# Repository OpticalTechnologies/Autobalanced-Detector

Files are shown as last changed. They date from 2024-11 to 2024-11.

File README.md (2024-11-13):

# Autobalanced-Detector
Full KiCAD design and production files of a self designed autobalanced detector for SRS microscopy. 

The autobalanced detector consists of three parts: 
1. Two of the same detectors (SRSDetV5_24V) to detect the signal and reference beam.
2. The autobalancer module.
3. The PID controller, which is designed as a seperate PCB controlled by an MCU. The MCU also controlls logic circuitry on the autobalancer module.

The SRSDetV5 is optimized for use with a 20MHz modulation frequency and incorperates several filters to supress the repetition rate of a 40MHz pulsed laser and its harmonics. 

Firmware for the PID MCU and instructions on how to upload the firmware to the MCU will follow.

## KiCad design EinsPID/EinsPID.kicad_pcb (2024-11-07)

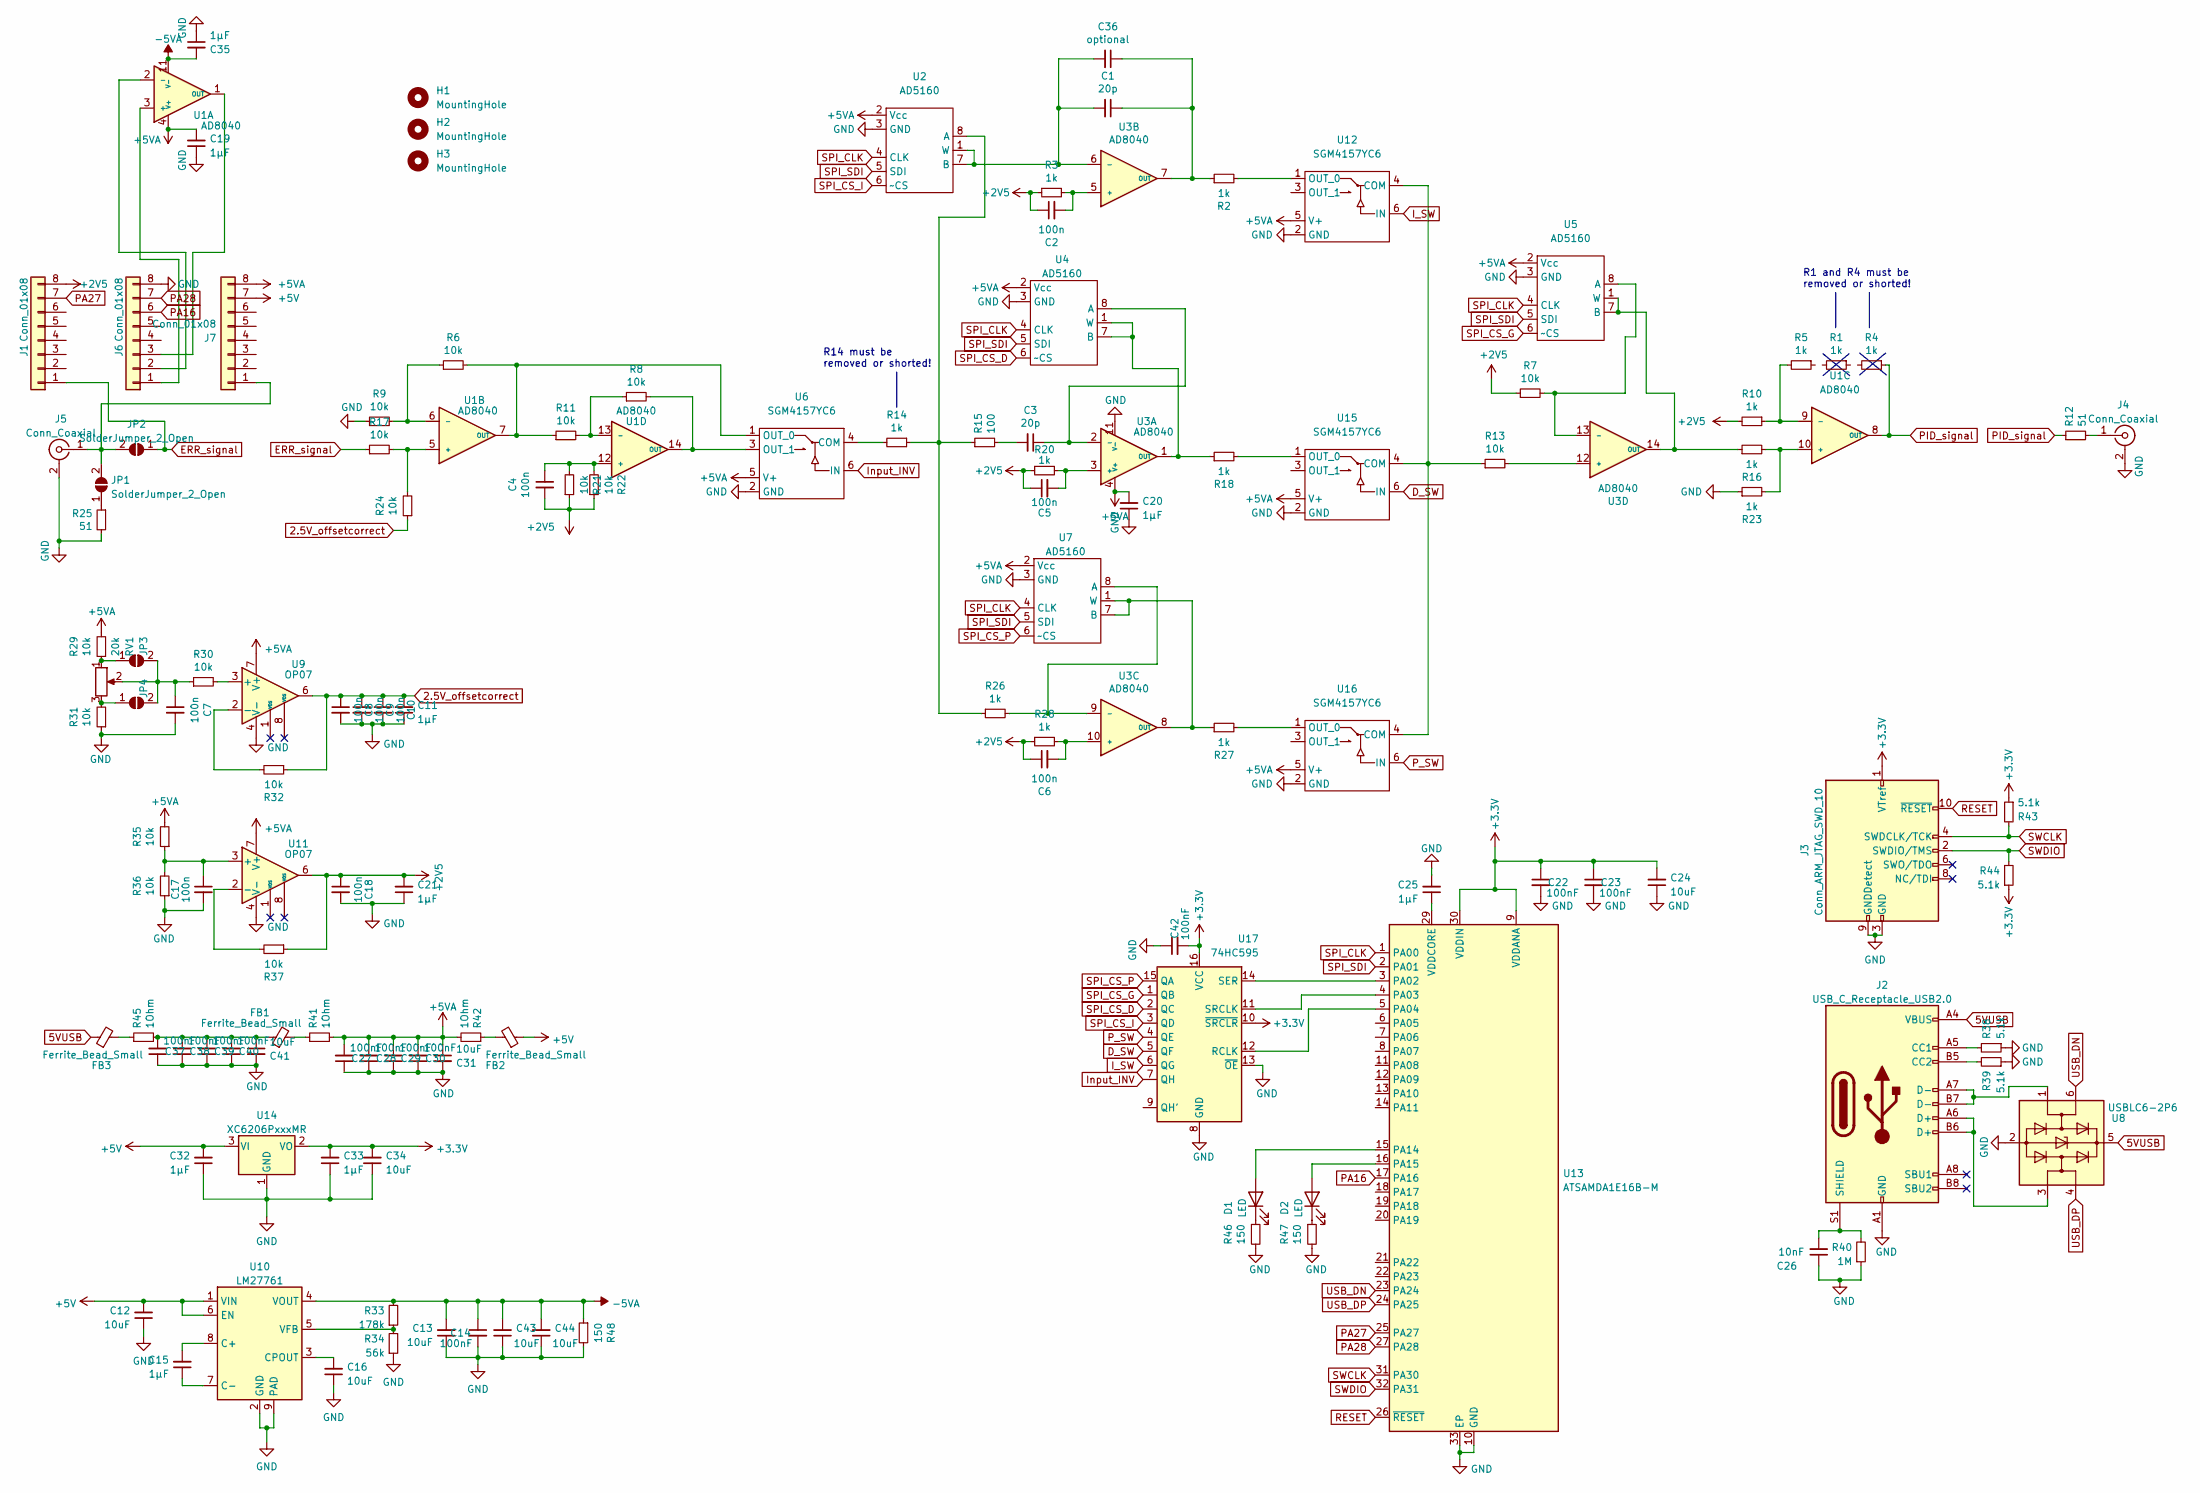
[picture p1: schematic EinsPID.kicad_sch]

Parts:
C1, C3: 20p; C_0402_1005Metric; LCSC C1554
C2, C4, C5, C6, C7, C8, C9, C10, C17, C18: 100n; C_0402_1005Metric; LCSC C1525
C11, C15, C19, C20, C21, C25, C32, C33, C35: 1µF; C_0402_1005Metric; LCSC C52923
C12, C13, C16, C24, C31, C34, C41, C43, C44: 10uF; C_0402_1005Metric; LCSC C386033
C14, C22, C23, C27, C28, C29, C30, C37, C38, C39, C40, C42: 100nF; C_0402_1005Metric; LCSC C307331
C26: 10nF; C_0402_1005Metric; LCSC C15195
C36: optional; C_Rect_L4.0mm_W2.5mm_P2.50mm
D1, D2: LED; LED_0603_1608Metric; LCSC C2286
FB1, FB2, FB3: Ferrite_Bead_Small; L_0603_1608Metric; LCSC C1002
H1: MountingHole; Logo_AGFallnich_text
H2: MountingHole; Logo_OptischeTechnologien
H3: MountingHole; Logo_WWU
J1, J6, J7: Conn_01x08; PinHeader_1x08_P2.54mm_Vertical
J2: USB_C_Receptacle_USB2.0; USB_C_Receptacle_XKB_U262-16XN-4BVC11; LCSC C709357
J3: Conn_ARM_JTAG_SWD_10; PinHeader_2x05_P1.27mm_Vertical_SMD
J4, J5: Conn_Coaxial; SMA_edge_pinholes
JP1, JP2, JP3, JP4: SolderJumper_2_Open; 0603_solderbridge
R1, R2, R3, R4, R5, R10, R14, R16, R18, R20, R23, R26, R27, R28: 1k; R_0402_1005Metric; LCSC C11702
R6, R7, R8, R9, R11, R13, R17, R21, R22, R24, R29, R30, R31, R32, R35, R36, R37: 10k; R_0402_1005Metric; LCSC C25744
R12, R25: 51; R_0402_1005Metric; LCSC C25125
R15: 100; R_0402_1005Metric; LCSC C25076
R33: 178k; R_0402_1005Metric; LCSC C26995
R34: 56k; R_0402_1005Metric; LCSC C25796
R38, R39, R43, R44: 5.1k; R_0402_1005Metric; LCSC C25905
R40: 1M; R_0402_1005Metric; LCSC C26083
R41, R42, R45: 1Ohm; R_0402_1005Metric; LCSC C25086
R46, R47, R48: 150; R_0402_1005Metric; LCSC C25082
RV1: 20k; Potentiometer_Bourns_3296W_Vertical
U1, U3: AD8040; SOIC-14_3.9x8.7mm_P1.27mm
U2, U4, U5, U7: AD5160; SOT-23-8; LCSC C40097
U6, U12, U15, U16: SGM4157YC6; SC-60; LCSC C124895
U8: USBLC6-2P6; SOT-666; LCSC C2827693
U9, U11: OP07; SOIC-8_3.9x4.9mm_P1.27mm; LCSC C7433
U10: LM27761; WSON-8-1EP_2x2mm_P0.5mm_EP0.9x1.6mm; LCSC C129351
U13: ATSAMDA1E16B-M; QFN-32-1EP_5x5mm_P0.5mm_EP3.6x3.6mm
U14: XC6206PxxxMR; SOT-23; LCSC C5446
U17: 74HC595; SOIC-16_3.9x9.9mm_P1.27mm; LCSC C5947

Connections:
2.5V_offsetcorrect: C8.1, C9.1, C10.1, C11.2, R24.1, R32.1, U9.6
5VUSB: FB3.1, J2.A4 (VBUS), J2.A9 (VBUS), J2.B4 (VBUS), J2.B9 (VBUS), U8.5 (VBUS)
+2V5: C2.1, C4.2, C5.1, C6.1, C18.1, C21.2, J1.8, R3.1, R7.1, R10.2, R20.1, R21.1, R22.1, R28.1, R37.1, U11.6
+3V3: C22.1, C23.1, C24.2, C33.2, C34.2, C42.2, J3.1 (VTref), R43.1, R44.1, U13.9 (VDDANA), U13.30 (VDDIN), U14.2 (VO), U17.10 (~SRCLR), U17.16 (VCC)
+5V: C12.2, C32.2, FB2.1, J7.7, U10.1 (VIN), U10.6 (EN), U14.3 (VI)
+5VA: C19.2, C20.2, C27.2, C28.2, C29.2, C30.2, C31.1, J7.8, R29.2, R35.2, R41.2, R42.2, U1.4 (V+), U2.2 (Vcc), U3.4 (V+), U4.2 (Vcc), U5.2 (Vcc), U6.5 (V+), U7.2 (Vcc), U9.7 (V+), U11.7 (V+), U12.5 (V+), U15.5 (V+), U16.5 (V+)
-5VA: C13.2, C14.1, C35.2, C43.2, C44.2, R33.2, R48.1, U1.11 (V-), U10.4 (VOUT)
D_SW: U15.6 (IN), U17.5 (QF)
ERR_signal: J1.1, JP2.1 (A), R17.1
GND: C7.2, C8.2, C9.2, C10.2, C11.1, C12.1, C13.1, C14.2, C16.1, C17.2, C18.2, C19.1, C20.1, C21.1, C22.2, C23.2, C24.1, C25.2, C26.1, C27.1, C28.1, C29.1, C30.1, C31.2, C32.1, C33.1, C34.1, C35.1, C37.1, C38.1, C39.1, C40.1, C41.2, C42.1, C43.1, C44.1, J2.A1 (GND), J2.A12 (GND), J2.B1 (GND), J2.B12 (GND), J3.3 (GND), J3.5 (GND), J3.9 (GNDDetect), J4.2 (Ext), J5.2 (Ext), J6.8, R9.1, R23.1, R25.2, R31.1, R34.1, R36.1, R38.1, R39.1, R40.1, R46.2, R47.2, R48.2, U2.3 (GND), U3.11 (V-), U4.3 (GND), U5.3 (GND), U6.2 (GND), U7.3 (GND), U8.2 (GND), U9.4 (V-), U10.2 (GND), U10.9 (PAD), U11.4 (V-), U12.2 (GND), U13.10 (GND), U13.28 (GND), U13.33 (EP), U14.1 (GND), U15.2 (GND), U16.2 (GND), U17.8 (GND), U17.13 (~OE)
I_SW: U12.6 (IN), U17.6 (QG)
Input_INV: U6.6 (IN), U17.7 (QH)
unnamed: C1.1, C36.1, R2.1, U3.7 (OUT)
unnamed: C1.2, C36.2, U2.1 (W), U2.7 (B), U3.6 (-)
unnamed: C2.2, R3.2, U3.5 (+)
unnamed: C3.1, U3.2 (-), U4.8 (A)
unnamed: C3.2, R15.2
unnamed: C4.1, R21.2, R22.2, U1.12 (+)
unnamed: C5.2, R20.2, U3.3 (+)
unnamed: C6.2, R28.2, U3.10 (+)
unnamed: C7.1, JP3.2 (B), JP4.2 (B), R30.1, RV1.2
unnamed: C15.1, U10.7 (C-)
unnamed: C15.2, U10.8 (C+)
unnamed: C16.2, U10.3 (CPOUT)
unnamed: C17.1, R35.1, R36.2, U11.3 (+)
unnamed: C25.1, U13.29 (VDDCORE)
unnamed: C26.2, J2.S1 (SHIELD), R40.2
unnamed: C37.2, C38.2, C39.2, C40.2, C41.1, FB1.1, R45.2
unnamed: D1.1 (K), R46.1
unnamed: D1.2 (A), U13.15 (PA14)
unnamed: D2.1 (K), R47.1
unnamed: D2.2 (A), U13.16 (PA15)
unnamed: FB1.2, R41.1
unnamed: FB2.2, R42.1
unnamed: FB3.2, R45.1
unnamed: J2.A5 (CC1), R38.2
unnamed: J2.A6 (D+), J2.B6 (D+), U8.3 (I/O2)
unnamed: J2.A7 (D-), J2.B7 (D-), U8.1 (I/O1)
unnamed: J2.B5 (CC2), R39.2
unnamed: J4.1 (In), R12.2
unnamed: J5.1 (In), J7.1, JP1.2 (B), JP2.2 (B)
unnamed: J6.1, U1.3 (+)
unnamed: J6.2, U1.2 (-)
unnamed: J6.3, U1.1 (OUT)
unnamed: JP1.1 (A), R25.1
unnamed: JP3.1 (A), R29.1, RV1.1
unnamed: JP4.1 (A), R31.2, RV1.3
unnamed: R1.1, R4.2
unnamed: R1.2, R5.1
unnamed: R2.2, U12.1 (OUT_0)
unnamed: R6.1, R9.2, U1.6 (-)
unnamed: R7.2, U3.13 (-), U5.8 (A)
unnamed: R8.2, U1.14 (OUT), U6.3 (OUT_1)
unnamed: R5.2, R10.1, U1.9 (-)
unnamed: R6.2, R11.1, U1.7 (OUT), U6.1 (OUT_0)
unnamed: R8.1, R11.2, U1.13 (-)
unnamed: R13.1, U12.4 (COM), U15.4 (COM), U16.4 (COM)
unnamed: R13.2, U3.12 (+)
unnamed: R14.1, R15.1, R26.1, U2.8 (A)
unnamed: R16.1, U3.14 (OUT), U5.1 (W), U5.7 (B)
unnamed: R16.2, R23.2, U1.10 (+)
unnamed: R17.2, R24.2, U1.5 (+)
unnamed: R18.1, U3.1 (OUT), U4.1 (W), U4.7 (B)
unnamed: R18.2, U15.1 (OUT_0)
unnamed: R26.2, U3.9 (-), U7.8 (A)
unnamed: R27.1, U3.8 (OUT), U7.1 (W), U7.7 (B)
unnamed: R27.2, U16.1 (OUT_0)
unnamed: R30.2, U9.3 (+)
unnamed: R32.2, U9.2 (-)
unnamed: R33.1, R34.2, U10.5 (VFB)
unnamed: R37.2, U11.2 (-)
unnamed: R14.2, U6.4 (COM)
unnamed: U13.3 (PA02), U17.14 (SER)
unnamed: U13.4 (PA03), U17.11 (SRCLK)
unnamed: U13.5 (PA04), U17.12 (RCLK)
PA16: J6.6, U13.17 (PA16)
PA27: J1.7, U13.25 (PA27)
PA28: J6.7, U13.27 (PA28)
PID_signal: R4.1, R12.1, U1.8 (OUT)
P_SW: U16.6 (IN), U17.4 (QE)
RESET: J3.10 (~RESET), U13.26 (~RESET)
SPI_CLK: U2.4 (CLK), U4.4 (CLK), U5.4 (CLK), U7.4 (CLK), U13.1 (PA00)
SPI_CS_D: U4.6 (~CS), U17.2 (QC)
SPI_CS_G: U5.6 (~CS), U17.1 (QB)
SPI_CS_I: U2.6 (~CS), U17.3 (QD)
SPI_CS_P: U7.6 (~CS), U17.15 (QA)
SPI_SDI: U2.5 (SDI), U4.5 (SDI), U5.5 (SDI), U7.5 (SDI), U13.2 (PA01)
SWCLK: J3.4 (SWDCLK/TCK), R43.2, U13.31 (PA30)
SWDIO: J3.2 (SWDIO/TMS), R44.2, U13.32 (PA31)
USB_DN: U8.6 (I/O1), U13.23 (PA24)
USB_DP: U8.4 (I/O2), U13.24 (PA25)

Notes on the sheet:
R14 must be removed or shorted!
R1 and R4 must be removed or shorted!

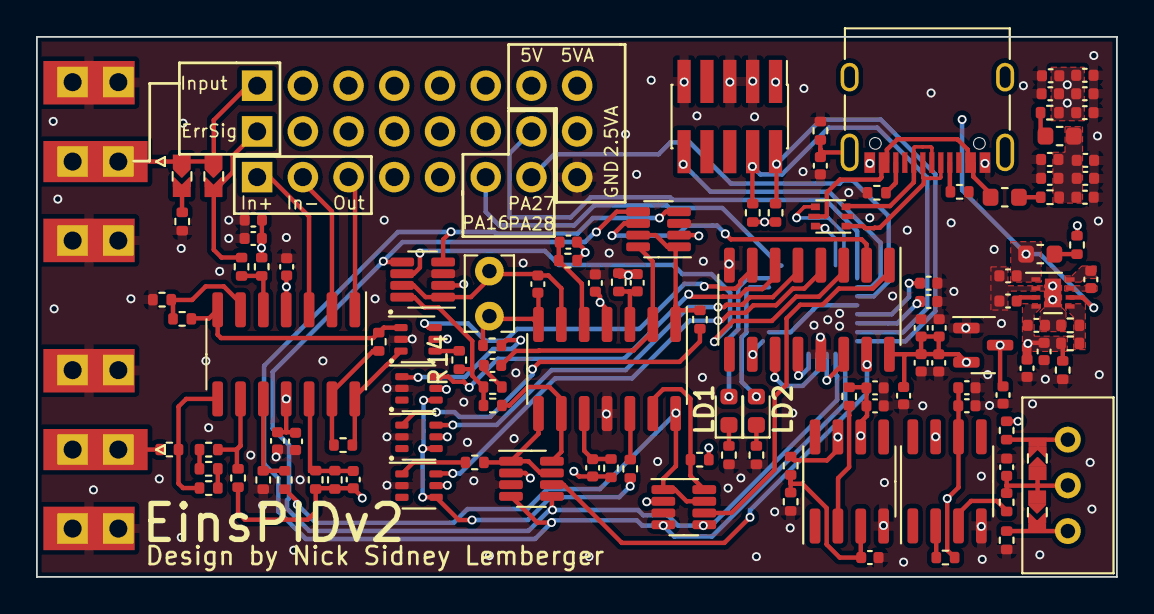
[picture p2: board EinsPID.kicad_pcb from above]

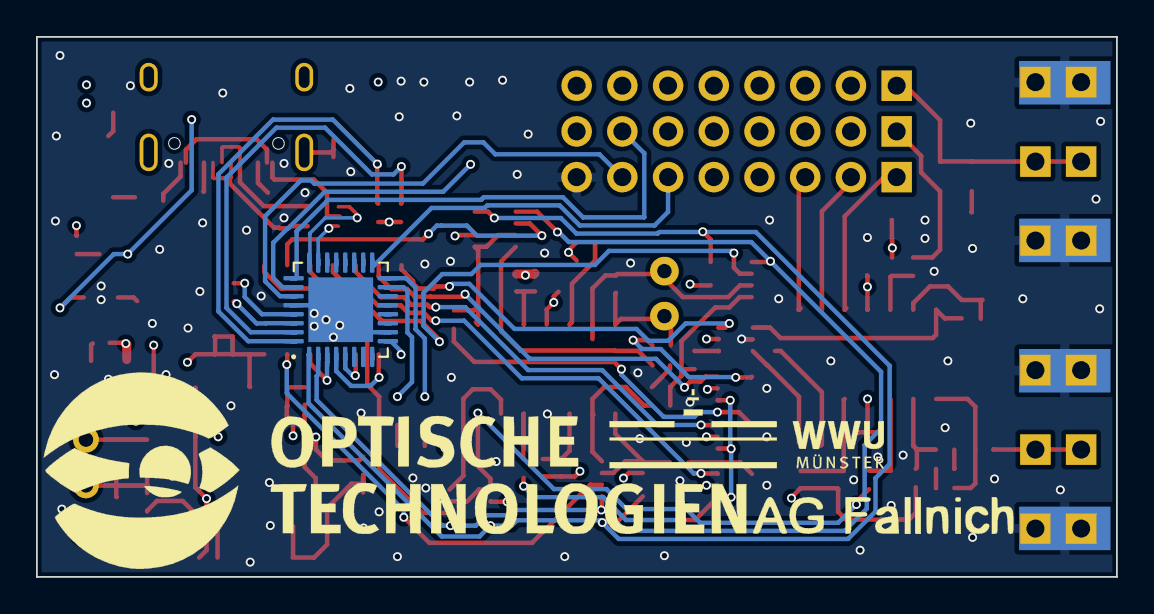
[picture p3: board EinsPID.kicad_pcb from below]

Board: 4 copper layers, 60.0 x 30.0 mm, 128 parts (4 on the bottom side), 91 nets.

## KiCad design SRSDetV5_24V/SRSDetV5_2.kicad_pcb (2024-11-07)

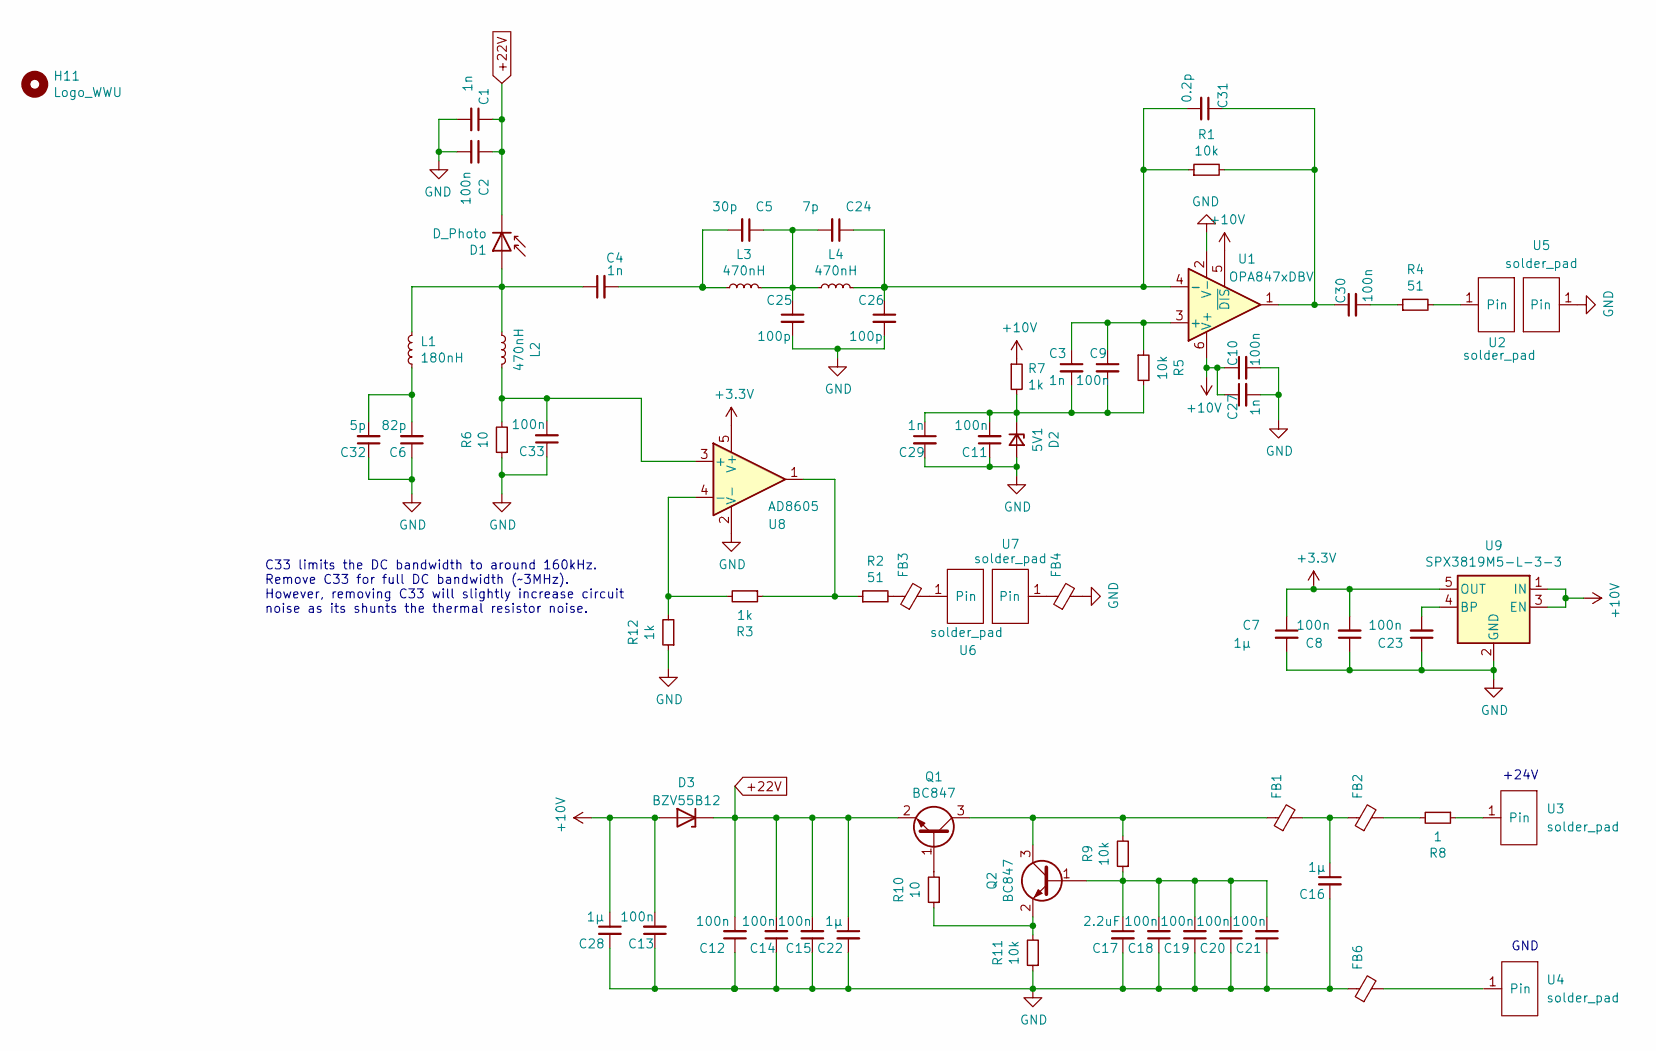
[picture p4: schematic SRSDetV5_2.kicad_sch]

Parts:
C1, C3, C4, C27, C29: 1n; C_0402_1005Metric; LCSC C1523
C2, C8, C9, C10, C11, C12, C13, C14, C15, C18, C19, C20, C21, C23, C30, C33: 100n; C_0402_1005Metric; LCSC C1525
C5: 30p; C_0402_1005Metric; LCSC C1570
C6: 82p; C_0402_1005Metric; LCSC C13532
C7, C16, C22, C28: 1µ; C_0402_1005Metric; LCSC C52923
C17: 2.2uF; C_1206_3216Metric; LCSC C50254
C24: 7p; C_0402_1005Metric; LCSC C114403
C25, C26: 100p; C_0402_1005Metric; LCSC C1546
C31: 0.2p; C_0402_1005Metric; LCSC C161339
C32: 5p; C_0402_1005Metric; LCSC C880630
D1: D_Photo; S3590-xx
D2: 5V1; D_SOD-323; LCSC C173436
D3: BZV55B12; D_MiniMELF; LCSC C545385
FB1, FB2, FB3, FB4, FB6: Ferrite_Bead_Small; L_0603_1608Metric; LCSC C1002
H11: Logo_WWU
L1: 180nH; L_0805_2012Metric; LCSC C251836
L2, L3, L4: 470nH; L_0603_1608Metric; LCSC C127457
Q1, Q2: BC847; SOT-23; LCSC C8664
R1: 10k; R_0402_1005Metric; LCSC C84351
R2, R4: 51; R_0402_1005Metric; LCSC C25125
R3, R7, R12: 1k; R_0402_1005Metric; LCSC C328418
R5, R9, R11: 10k; R_0402_1005Metric; LCSC C25744
R6: 10; R_0402_1005Metric; LCSC C319916
R8: 1; R_0402_1005Metric; LCSC C25086
R10: 10; R_0402_1005Metric; LCSC C25077
U1: OPA847xDBV; SOT-23-6; LCSC C160422
U2, U3, U4, U5, U6, U7: solder_pad
U8: AD8605; SOT-23-5; LCSC C9641
U9: SPX3819M5-L-3-3; SOT-23-5; LCSC C9055

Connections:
+3V3: C7.1, C8.2, U8.5 (V+), U9.5 (OUT)
+10V: C10.1, C13.2, C27.1, C28.1, D3.2 (A), R7.1, U1.5 (~DIS), U1.6 (V+), U9.1 (IN), U9.3 (EN)
+22V: C1.1, C2.1, C12.2, C14.2, C15.2, C22.1, D1.1 (K), D3.1 (K), Q1.2 (E)
GND: C1.2, C2.2, C6.1, C7.2, C8.1, C10.2, C11.1, C12.1, C13.1, C14.1, C15.1, C16.2, C17.2, C18.1, C19.1, C20.1, C21.1, C22.2, C23.1, C25.2, C26.2, C27.2, C28.2, C29.2, C32.1, C33.1, D2.2 (A), FB4.2, FB6.1, R6.1, R11.1, R12.1, U1.2 (V-), U5.1, U8.2 (V-), U9.2 (GND)
unnamed: C3.1, C9.1, R5.1, U1.3 (+)
unnamed: C4.1, D1.2 (A), L1.2, L2.1
unnamed: C4.2, C5.2, L3.1
unnamed: C3.2, C9.2, C11.2, C29.1, D2.1 (K), R5.2, R7.2
unnamed: C16.1, FB1.2, FB2.1
unnamed: C17.1, C18.2, C19.2, C20.2, C21.2, Q2.1 (B), R9.1
unnamed: C23.2, U9.4 (BP)
unnamed: C24.1, C26.1, C31.2, L4.2, R1.1, U1.4 (-)
unnamed: C5.1, C24.2, C25.1, L3.2, L4.1
unnamed: C30.1, C31.1, R1.2, U1.1
unnamed: C30.2, R4.1
unnamed: C6.2, C32.2, L1.1
unnamed: C33.2, L2.2, R6.2, U8.3 (+)
unnamed: FB1.1, Q1.3 (C), Q2.3 (C), R9.2
unnamed: FB2.2, R8.2
unnamed: FB3.1, R2.2
unnamed: FB3.2, U6.1
unnamed: FB4.1, U7.1
unnamed: Q1.1 (B), R10.2
unnamed: Q2.2 (E), R10.1, R11.2
unnamed: R2.1, R3.1, U8.1
unnamed: R4.2, U2.1
unnamed: R8.1, U3.1
unnamed: R3.2, R12.2, U8.4 (-)

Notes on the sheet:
+24V
C33 limits the DC bandwidth to around 160kHz. Remove C33 for full DC bandwidth (~3MHz). However, removing C33 will slightly increase circuit noise as its shunts the thermal resistor noise.
GND

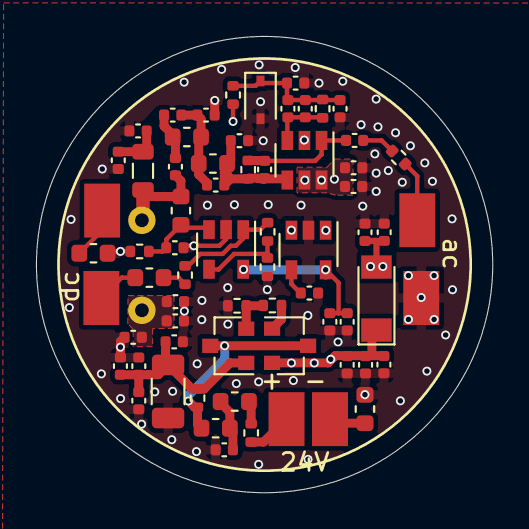
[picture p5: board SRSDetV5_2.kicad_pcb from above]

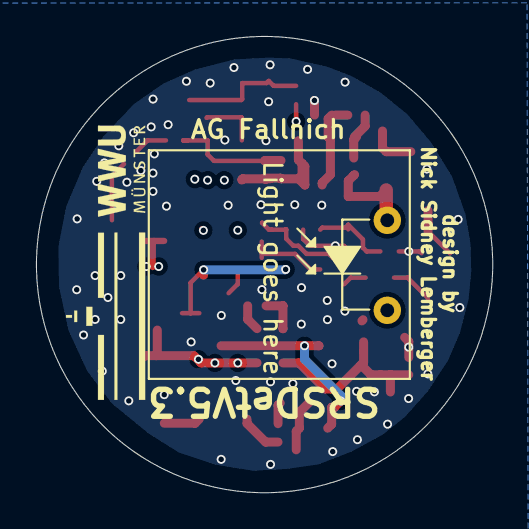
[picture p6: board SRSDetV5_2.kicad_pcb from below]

Board: 4 copper layers, 25.3 x 25.3 mm, 69 parts (2 on the bottom side), 28 nets.

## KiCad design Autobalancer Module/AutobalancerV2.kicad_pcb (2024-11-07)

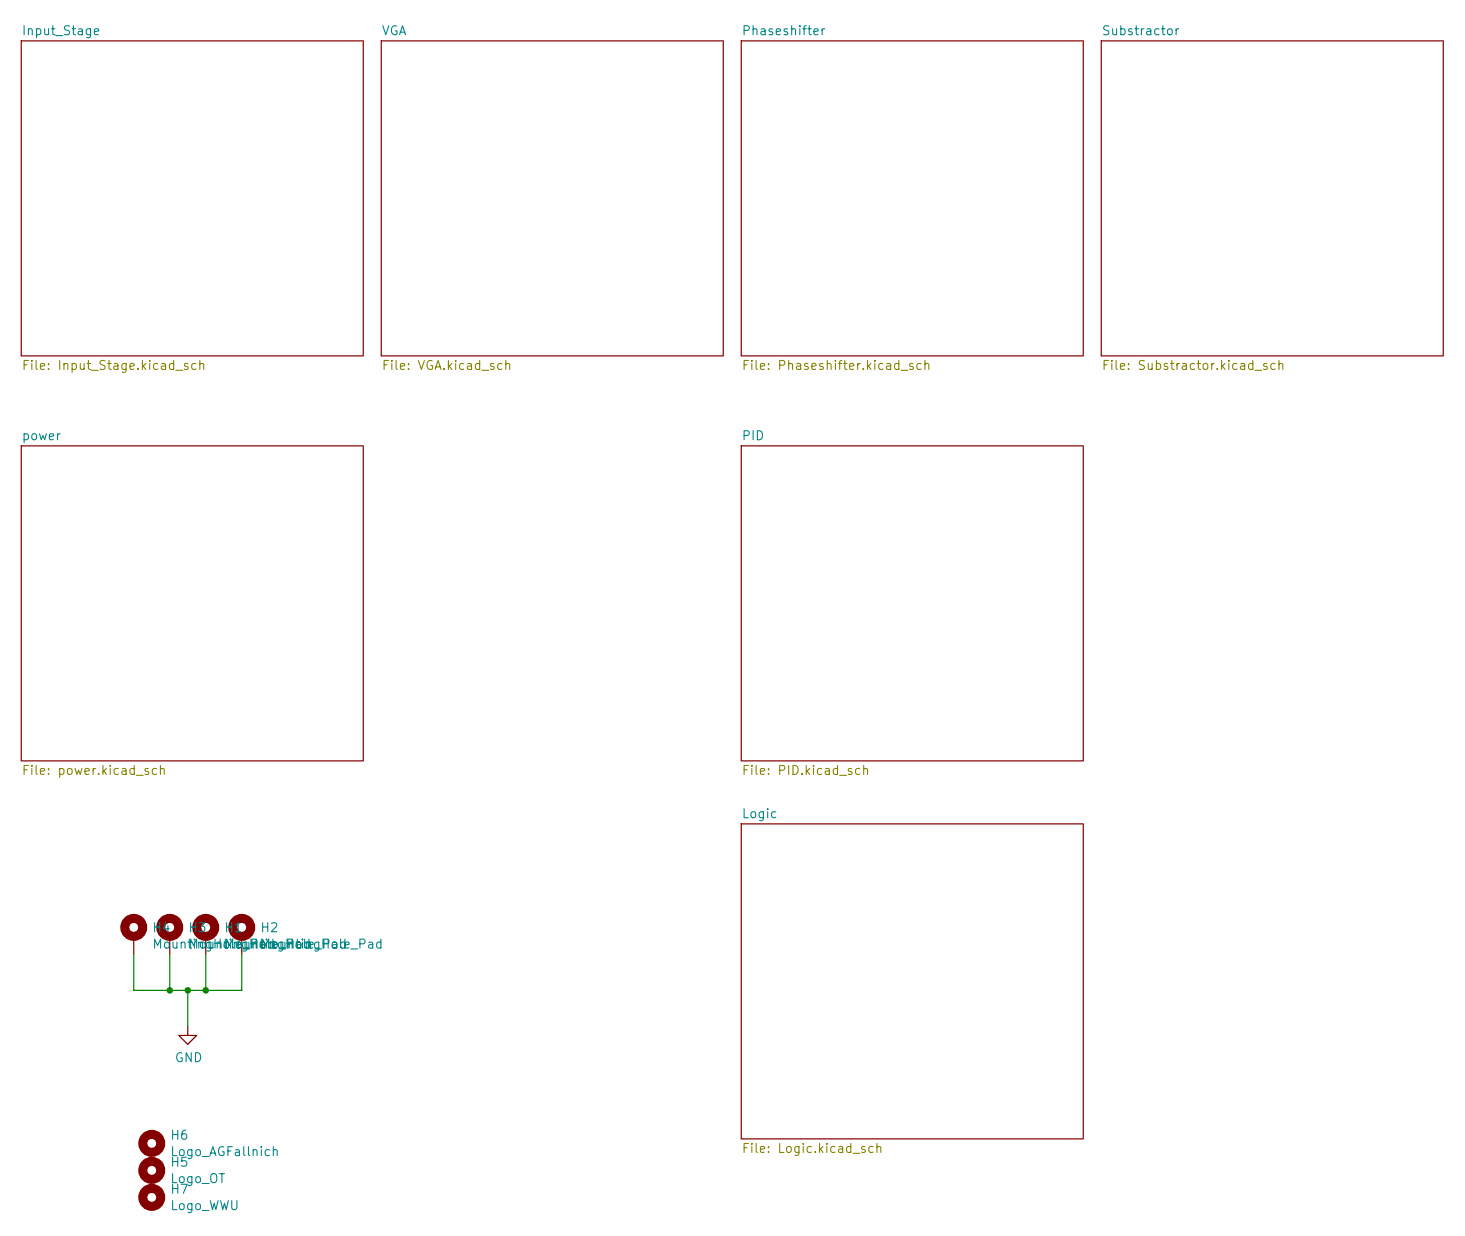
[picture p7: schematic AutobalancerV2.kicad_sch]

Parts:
H1, H2, H3, H4: MountingHole_Pad; MountingHole_3.2mm_M3_Pad_Via
H5: Logo_OT; Logo_OptischeTechnologien
H6: Logo_AGFallnich; Logo_AGFallnich_text
H7: Logo_WWU

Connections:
GND: H1.1, H2.1, H3.1, H4.1; also elsewhere on the board

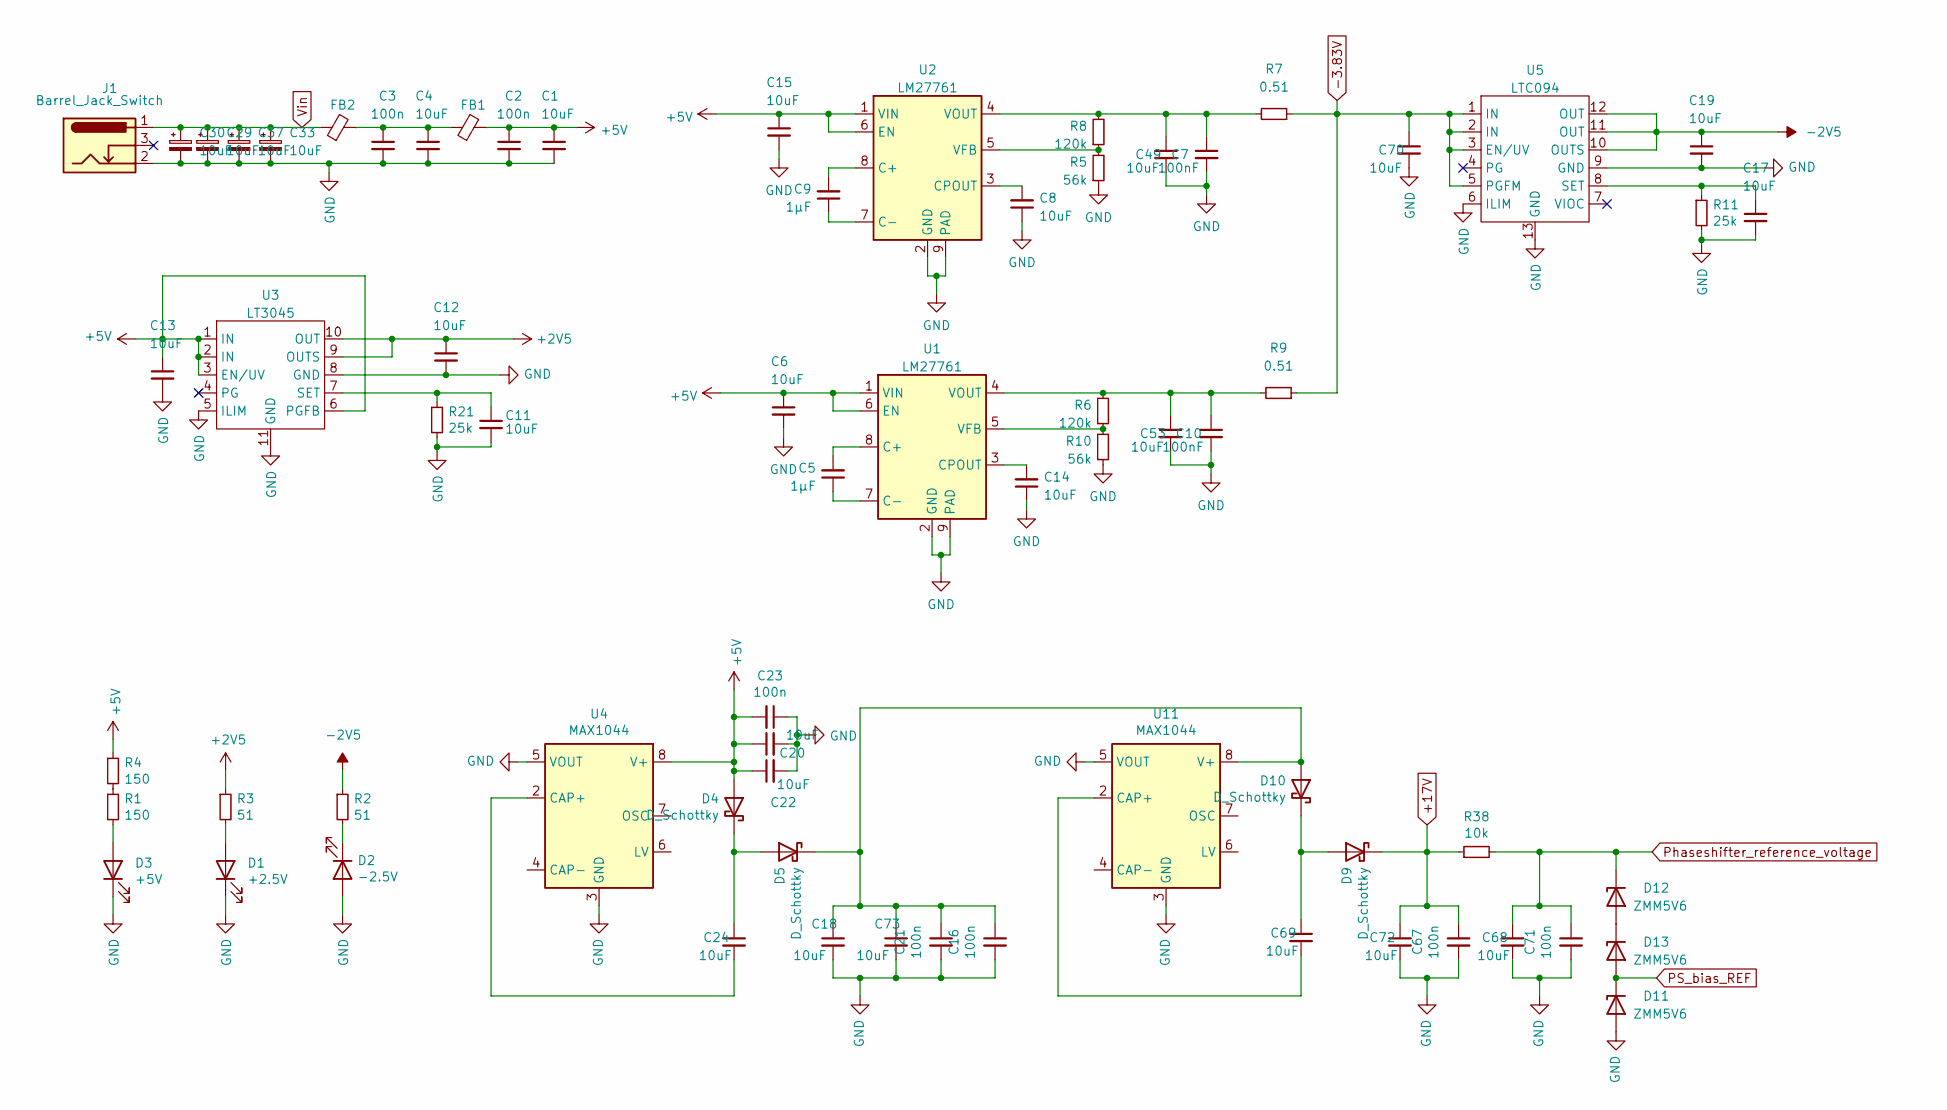
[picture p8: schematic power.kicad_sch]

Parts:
C1, C4, C6, C11, C12, C13, C15, C17, C18, C19, C20, C22, C24, C49, C53, C68, C69, C70, C72, C73: 10uF; C_1206_3216Metric; LCSC C13585
C2, C3, C16, C21, C23, C67, C71: 100n; C_0402_1005Metric; LCSC C1525
C5, C9: 1µF; C_0402_1005Metric; LCSC C52923
C7, C10: 100nF; C_0402_1005Metric; LCSC C307331
C8, C14: 10uF; C_0402_1005Metric; LCSC C386033
C29, C30, C33, C37: 10uF; CP_EIA-3216-18_Kemet-A; LCSC C7171
D1: +2.5V; LED_0603_1608Metric; LCSC C2286
D2: -2.5V; LED_0603_1608Metric; LCSC C2286
D3: +5V; LED_0603_1608Metric; LCSC C2286
D4, D5, D9, D10: D_Schottky; D_SOD-123; LCSC C8598
D11, D12, D13: ZMM5V6; D_MiniMELF; LCSC C8062
FB1, FB2: Ferrite_Bead_Small; L_0805_2012Metric; LCSC C74323
J1: Barrel_Jack_Switch; BarrelJack_CUI_PJ-102AH_Horizontal_with3D
R1, R4: 150; R_0402_1005Metric; LCSC C25082
R2, R3: 51; R_0402_1005Metric; LCSC C25125
R5, R10: 56k; R_0402_1005Metric; LCSC C25796
R6, R8: 120k; R_0402_1005Metric; LCSC C25750
R7, R9: 0.51; R_0402_1005Metric; LCSC C423100
R11, R21: 25k; R_0805_2012Metric; LCSC C316201
R38: 10k; R_0402_1005Metric; LCSC C25744
U1, U2: LM27761; WSON-8-1EP_2x2mm_P0.5mm_EP0.9x1.6mm; LCSC C129351
U3: LT3045; DFN-10-1EP_3x3mm_P0.5mm_EP1.65x2.38mm; LCSC C666574
U4, U11: MAX1044; SOIC-8_3.9x4.9mm_P1.27mm; LCSC C140450
U5: LTC094; DFN-12-1EP_3x3mm_P0.45mm_EP1.66x2.38mm

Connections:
+2V5: C12.1, R3.1, U3.9 (OUTS), U3.10 (OUT); also elsewhere on the board
+5V: C1.1, C2.1, C6.1, C13.1, C15.1, C20.1, C22.1, C23.2, D4.2 (A), FB1.2, R4.1, U1.1 (VIN), U1.6 (EN), U2.1 (VIN), U2.6 (EN), U3.1 (IN), U3.2 (IN), U3.3 (EN/UV), U3.6 (PGFB), U4.8 (V+); also elsewhere on the board
+17V: C67.1, C72.1, D9.1 (K), R38.1; also elsewhere on the board
-2V5: C19.1, R2.1, U5.10 (OUTS), U5.11 (OUT), U5.12 (OUT); also elsewhere on the board
-3.83V: C70.1, R7.1, R9.1, U5.1 (IN), U5.2 (IN), U5.3 (EN/UV), U5.5 (PGFM)
GND: C1.2, C2.2, C3.2, C4.2, C6.2, C7.2, C8.1, C10.2, C11.2, C12.2, C13.2, C14.1, C15.2, C16.2, C17.2, C18.2, C19.2, C20.2, C21.2, C22.2, C23.1, C29.2, C30.2, C33.2, C37.2, C49.2, C53.2, C67.2, C68.2, C70.2, C71.2, C72.2, C73.2, D1.1 (K), D2.2 (A), D3.1 (K), D11.2 (A), J1.2, R5.1, R10.1, R11.2, R21.2, U1.2 (GND), U1.9 (PAD), U2.2 (GND), U2.9 (PAD), U3.5 (ILIM), U3.8 (GND), U3.11 (GND), U4.3 (GND), U4.5 (VOUT), U5.6 (ILIM), U5.9 (GND), U5.13 (GND), U11.3 (GND), U11.5 (VOUT); also elsewhere on the board
unnamed: C3.1, C4.1, FB1.1, FB2.2
unnamed: C5.1, U1.7 (C-)
unnamed: C5.2, U1.8 (C+)
unnamed: C8.2, U2.3 (CPOUT)
unnamed: C9.1, U2.7 (C-)
unnamed: C9.2, U2.8 (C+)
unnamed: C10.1, C53.1, R6.2, R9.2, U1.4 (VOUT)
unnamed: C11.1, R21.1, U3.7 (SET)
unnamed: C14.2, U1.3 (CPOUT)
unnamed: C16.1, C18.1, C21.1, C73.1, D5.1 (K), D10.2 (A), U11.8 (V+)
unnamed: C17.1, R11.1, U5.8 (SET)
unnamed: C24.1, D4.1 (K), D5.2 (A)
unnamed: C24.2, U4.2 (CAP+)
unnamed: C7.1, C49.1, R7.2, R8.2, U2.4 (VOUT)
unnamed: C69.1, D9.2 (A), D10.1 (K)
unnamed: C69.2, U11.2 (CAP+)
unnamed: D1.2 (A), R3.2
unnamed: D2.1 (K), R2.2
unnamed: D3.2 (A), R1.2
unnamed: D12.2 (A), D13.1 (K)
unnamed: R1.1, R4.2
unnamed: R5.2, R8.1, U2.5 (VFB)
unnamed: R6.1, R10.2, U1.5 (VFB)
PS_bias_REF: D11.1 (K), D13.2 (A); also elsewhere on the board
Phaseshifter_reference_voltage: C68.1, C71.1, D12.1 (K), R38.2; also elsewhere on the board
Vin: C29.1, C30.1, C33.1, C37.1, FB2.1, J1.1; also elsewhere on the board

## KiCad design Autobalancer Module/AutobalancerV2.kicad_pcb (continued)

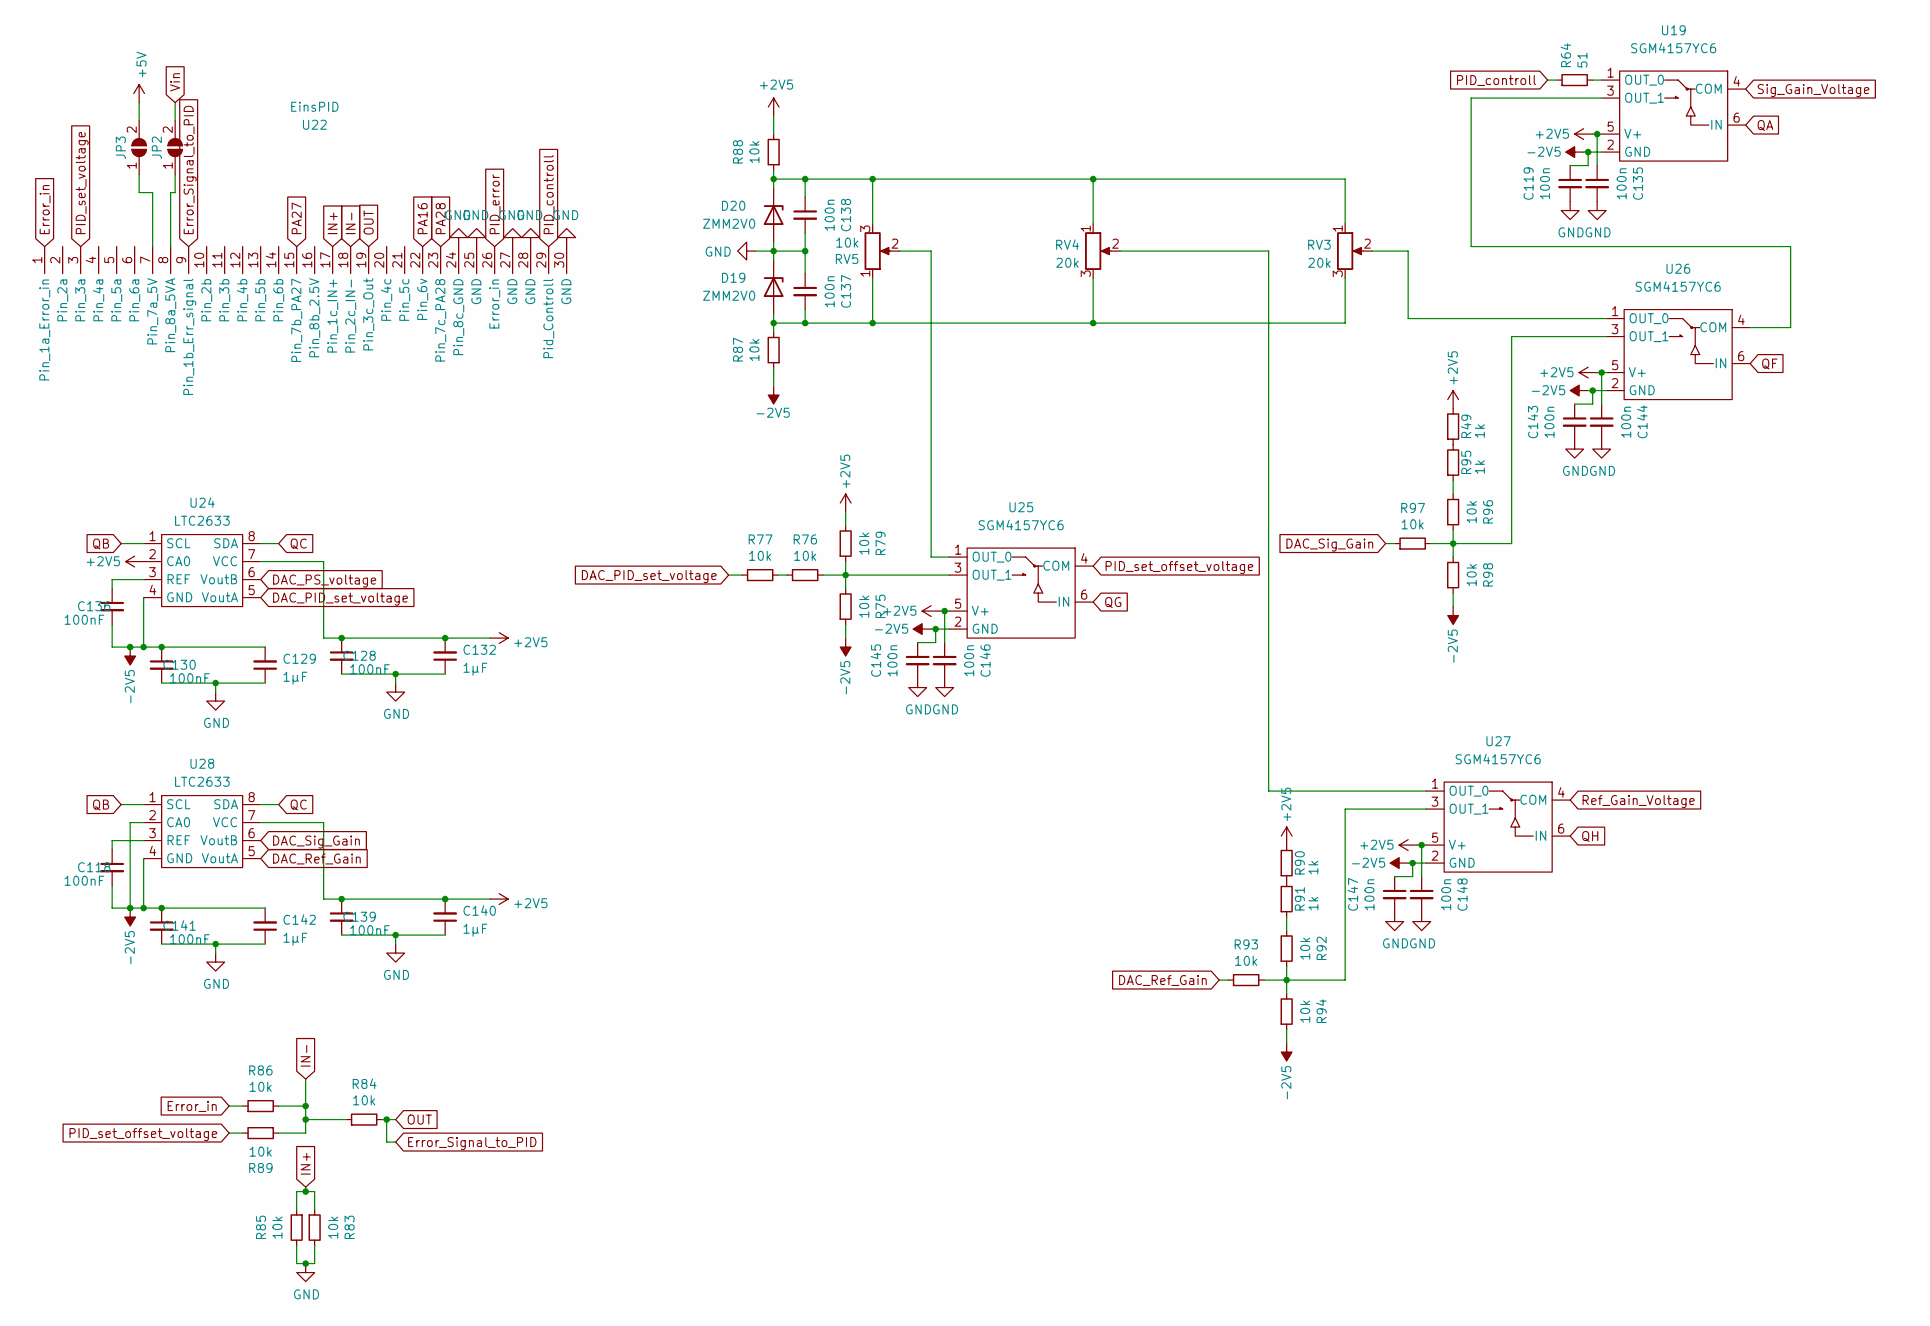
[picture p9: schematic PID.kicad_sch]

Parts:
C118, C128, C130, C136, C139, C141: 100nF; C_0402_1005Metric; LCSC C307331
C119, C135, C137, C138, C143, C144, C145, C146, C147, C148: 100n; C_0402_1005Metric; LCSC C1525
C129, C132, C140, C142: 1µF; C_0402_1005Metric; LCSC C52923
D19, D20: ZMM2V0; D_MiniMELF; LCSC C8079
JP2, JP3: SolderJumper_2_Open; 0603_solderbridge
R49, R90, R91, R95: 1k; R_0402_1005Metric; LCSC C11702
R64: 51; R_0402_1005Metric; LCSC C25125
R75, R76, R77, R79, R83, R84, R85, R86, R87, R88, R89, R92, R93, R94, R96, R97, R98: 10k; R_0402_1005Metric; LCSC C25744
RV3, RV4: 20k; Potentiometer_Bourns_3296W_Vertical
RV5: 10k; Potentiometer_Bourns_3296W_Vertical
U19, U25, U26, U27: SGM4157YC6; SC-60; LCSC C124895
U22: EinsPID
U24, U28: LTC2633; SOT-23-8

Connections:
+2V5: C128.1, C132.2, C135.1, C139.1, C140.2, C144.1, C146.1, C148.1, R49.2, R79.2, R88.2, R90.2, U19.5 (V+), U24.2 (CA0), U24.7 (VCC), U25.5 (V+), U26.5 (V+), U27.5 (V+), U28.7 (VCC); also elsewhere on the board
+5V: JP3.2 (B); also elsewhere on the board
-2V5: C118.2, C119.1, C129.2, C130.1, C136.2, C141.1, C142.2, C143.1, C145.1, C147.1, R75.1, R87.1, R94.1, R98.1, U19.2 (GND), U24.4 (GND), U25.2 (GND), U26.2 (GND), U27.2 (GND), U28.2 (CA0), U28.4 (GND); also elsewhere on the board
DAC_PID_set_voltage: R77.1, U24.5 (VoutA)
DAC_PS_voltage: U24.6 (VoutB); also elsewhere on the board
DAC_Ref_Gain: R93.1, U28.5 (VoutA)
DAC_Sig_Gain: R97.1, U28.6 (VoutB)
Error_Signal_to_PID: R84.2, U22.9 (Pin_1b_Err_signal), U22.19 (Pin_3c_Out)
Error_in: R86.1, U22.1 (Pin_1a_Error_in)
GND: C119.2, C128.2, C129.1, C130.2, C132.1, C135.2, C137.1, C138.2, C139.2, C140.1, C141.2, C142.1, C143.2, C144.2, C145.2, C146.2, C147.2, C148.2, D19.1 (K), D20.2 (A), R83.2, R85.2, U22.24 (Pin_8c_GND), U22.25 (GND), U22.27 (GND), U22.28 (GND), U22.30 (GND); also elsewhere on the board
IN+: R83.1, R85.1, U22.17 (Pin_1c_IN+)
IN-: R84.1, R86.2, R89.1, U22.18 (Pin_2c_IN-)
unnamed: C118.1, U28.3 (REF)
unnamed: C136.1, U24.3 (REF)
unnamed: C137.2, D19.2 (A), R87.2, RV3.3, RV4.3, RV5.1
unnamed: C138.1, D20.1 (K), R88.1, RV3.1, RV4.1, RV5.3
unnamed: JP2.1 (A), U22.8 (Pin_8a_5VA)
unnamed: JP3.1 (A), U22.7 (Pin_7a_5V)
unnamed: R49.1, R95.2
unnamed: R64.2, U19.1 (OUT_0)
unnamed: R75.2, R76.2, R79.1, U25.3 (OUT_1)
unnamed: R76.1, R77.2
unnamed: R90.1, R91.2
unnamed: R91.1, R92.2
unnamed: R92.1, R93.2, R94.2, U27.3 (OUT_1)
unnamed: R95.1, R96.2
unnamed: R96.1, R97.2, R98.2, U26.3 (OUT_1)
unnamed: RV3.2, U26.1 (OUT_0)
unnamed: RV4.2, U27.1 (OUT_0)
unnamed: RV5.2, U25.1 (OUT_0)
unnamed: U19.3 (OUT_1), U26.4 (COM)
PA16: U22.22 (Pin_6v); also elsewhere on the board
PA27: U22.15 (Pin_7b_PA27); also elsewhere on the board
PA28: U22.23 (Pin_7c_PA28); also elsewhere on the board
PID_controll: R64.1, U22.29 (Pid_Controll)
PID_error: U22.26 (Error_in); also elsewhere on the board
PID_set_offset_voltage: R89.2, U25.4 (COM)
PID_set_voltage: U22.3 (Pin_3a)
QA: U19.6 (IN); also elsewhere on the board
QB: U24.1 (SCL), U28.1 (SCL); also elsewhere on the board
QC: U24.8 (SDA), U28.8 (SDA); also elsewhere on the board
QF: U26.6 (IN); also elsewhere on the board
QG: U25.6 (IN); also elsewhere on the board
QH: U27.6 (IN); also elsewhere on the board
Ref_Gain_Voltage: U27.4 (COM); also elsewhere on the board
Sig_Gain_Voltage: U19.4 (COM); also elsewhere on the board
Vin: JP2.2 (B); also elsewhere on the board

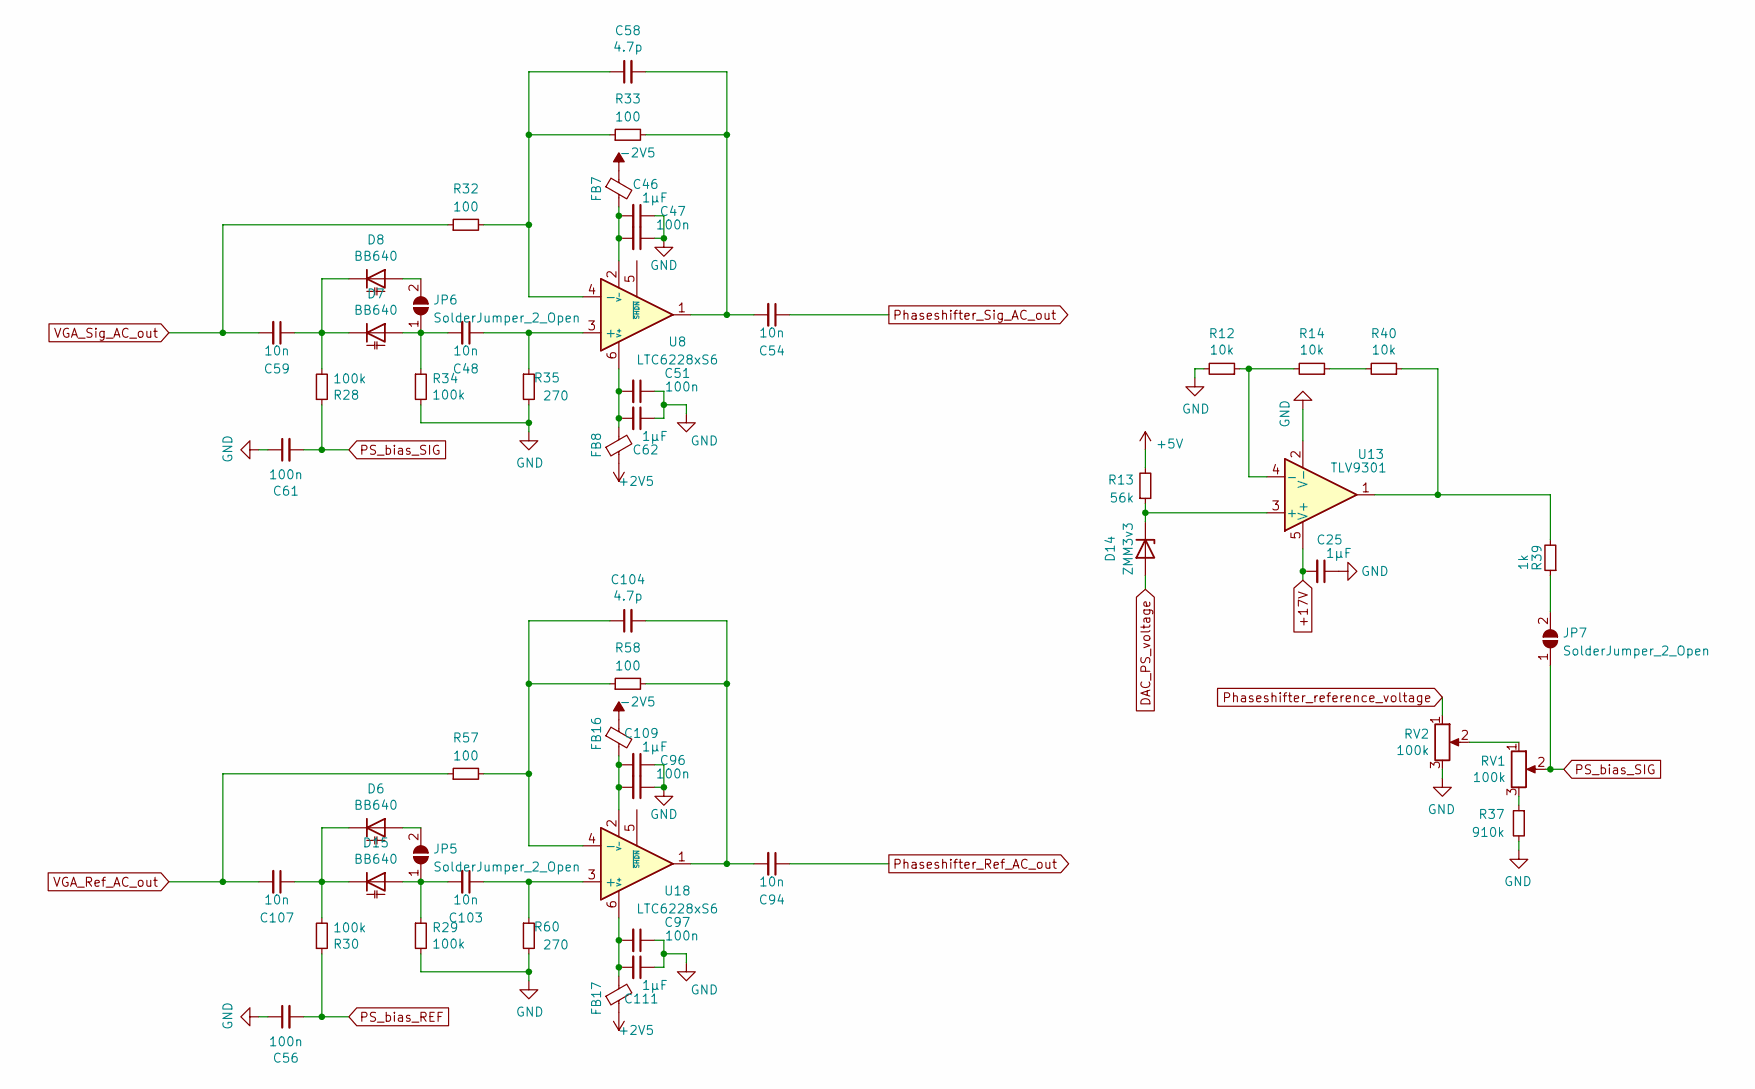
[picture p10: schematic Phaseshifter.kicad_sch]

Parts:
C25, C46, C62, C109, C111: 1µF; C_0402_1005Metric; LCSC C52923
C47, C51, C56, C61, C96, C97: 100n; C_0402_1005Metric; LCSC C1525
C48, C54, C59, C94, C103, C107: 10n; C_0402_1005Metric; LCSC C15195
C58, C104: 4.7p; C_0402_1005Metric; LCSC C1569
D6, D7, D8, D15: BB640; D_SOD-323F; LCSC C150932
D14: ZMM3v3; D_MiniMELF; LCSC C8056
FB7, FB8, FB16, FB17: Ferrite_Bead_Small; L_0603_1608Metric; LCSC C1002
JP5, JP6, JP7: SolderJumper_2_Open; 0603_solderbridge
R12, R14, R40: 10k; R_0402_1005Metric; LCSC C25744
R13: 56k; R_0402_1005Metric; LCSC C25796
R28, R29, R30, R34: 100k; R_0402_1005Metric; LCSC C25741
R32, R33, R57, R58: 100; R_0402_1005Metric; LCSC C25076
R35, R60: 270; R_0402_1005Metric; LCSC C25099
R37: 910k; R_0402_1005Metric; LCSC C25572
R39: 1k; R_0402_1005Metric; LCSC C11702
RV1, RV2: 100k; Potentiometer_Bourns_3296W_Vertical
U8, U18: LTC6228xS6; TSOT-23-6
U13: TLV9301; SOT-23-5; Mouser 595-TLV9301IDBVR

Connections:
+2V5: FB8.1, FB17.1; also elsewhere on the board
+5V: R13.2; also elsewhere on the board
+17V: C25.2, U13.5 (V+); also elsewhere on the board
-2V5: FB7.1, FB16.1; also elsewhere on the board
DAC_PS_voltage: D14.2 (A); also elsewhere on the board
GND: C25.1, C46.1, C47.1, C51.1, C56.1, C61.1, C62.1, C96.1, C97.1, C109.1, C111.1, R12.2, R29.2, R34.2, R35.2, R37.2, R60.2, RV2.3, U13.2 (V-); also elsewhere on the board
unnamed: C46.2, C47.2, FB7.2, U8.2 (V-)
unnamed: C48.1, R35.1, U8.3 (+)
unnamed: C48.2, D7.2 (A), JP6.1 (A), R34.1
unnamed: C51.2, C62.2, FB8.2, U8.6 (V+)
unnamed: C54.2, C58.2, R33.2, U8.1
unnamed: C58.1, R32.2, R33.1, U8.4 (-)
unnamed: C59.1, D7.1 (K), D8.1 (K), R28.2
unnamed: C103.1, R60.1, U18.3 (+)
unnamed: C103.2, D15.2 (A), JP5.1 (A), R29.1
unnamed: C104.1, R57.2, R58.1, U18.4 (-)
unnamed: C94.2, C104.2, R58.2, U18.1
unnamed: C107.1, D6.1 (K), D15.1 (K), R30.2
unnamed: C96.2, C109.2, FB16.2, U18.2 (V-)
unnamed: C97.2, C111.2, FB17.2, U18.6 (V+)
unnamed: D6.2 (A), JP5.2 (B)
unnamed: D8.2 (A), JP6.2 (B)
unnamed: D14.1 (K), R13.1, U13.3 (+)
unnamed: JP7.2 (B), R39.1
unnamed: R12.1, R14.2, U13.4 (-)
unnamed: R14.1, R40.2
unnamed: R37.1, RV1.3
unnamed: R39.2, R40.1, U13.1
unnamed: RV1.1, RV2.2
PS_bias_REF: C56.2, R30.1; also elsewhere on the board
PS_bias_SIG: C61.2, JP7.1 (A), R28.1, RV1.2
Phaseshifter_Ref_AC_out: C94.1; also elsewhere on the board
Phaseshifter_Sig_AC_out: C54.1; also elsewhere on the board
Phaseshifter_reference_voltage: RV2.1; also elsewhere on the board
VGA_Ref_AC_out: C107.2, R57.1; also elsewhere on the board
VGA_Sig_AC_out: C59.2, R32.1; also elsewhere on the board

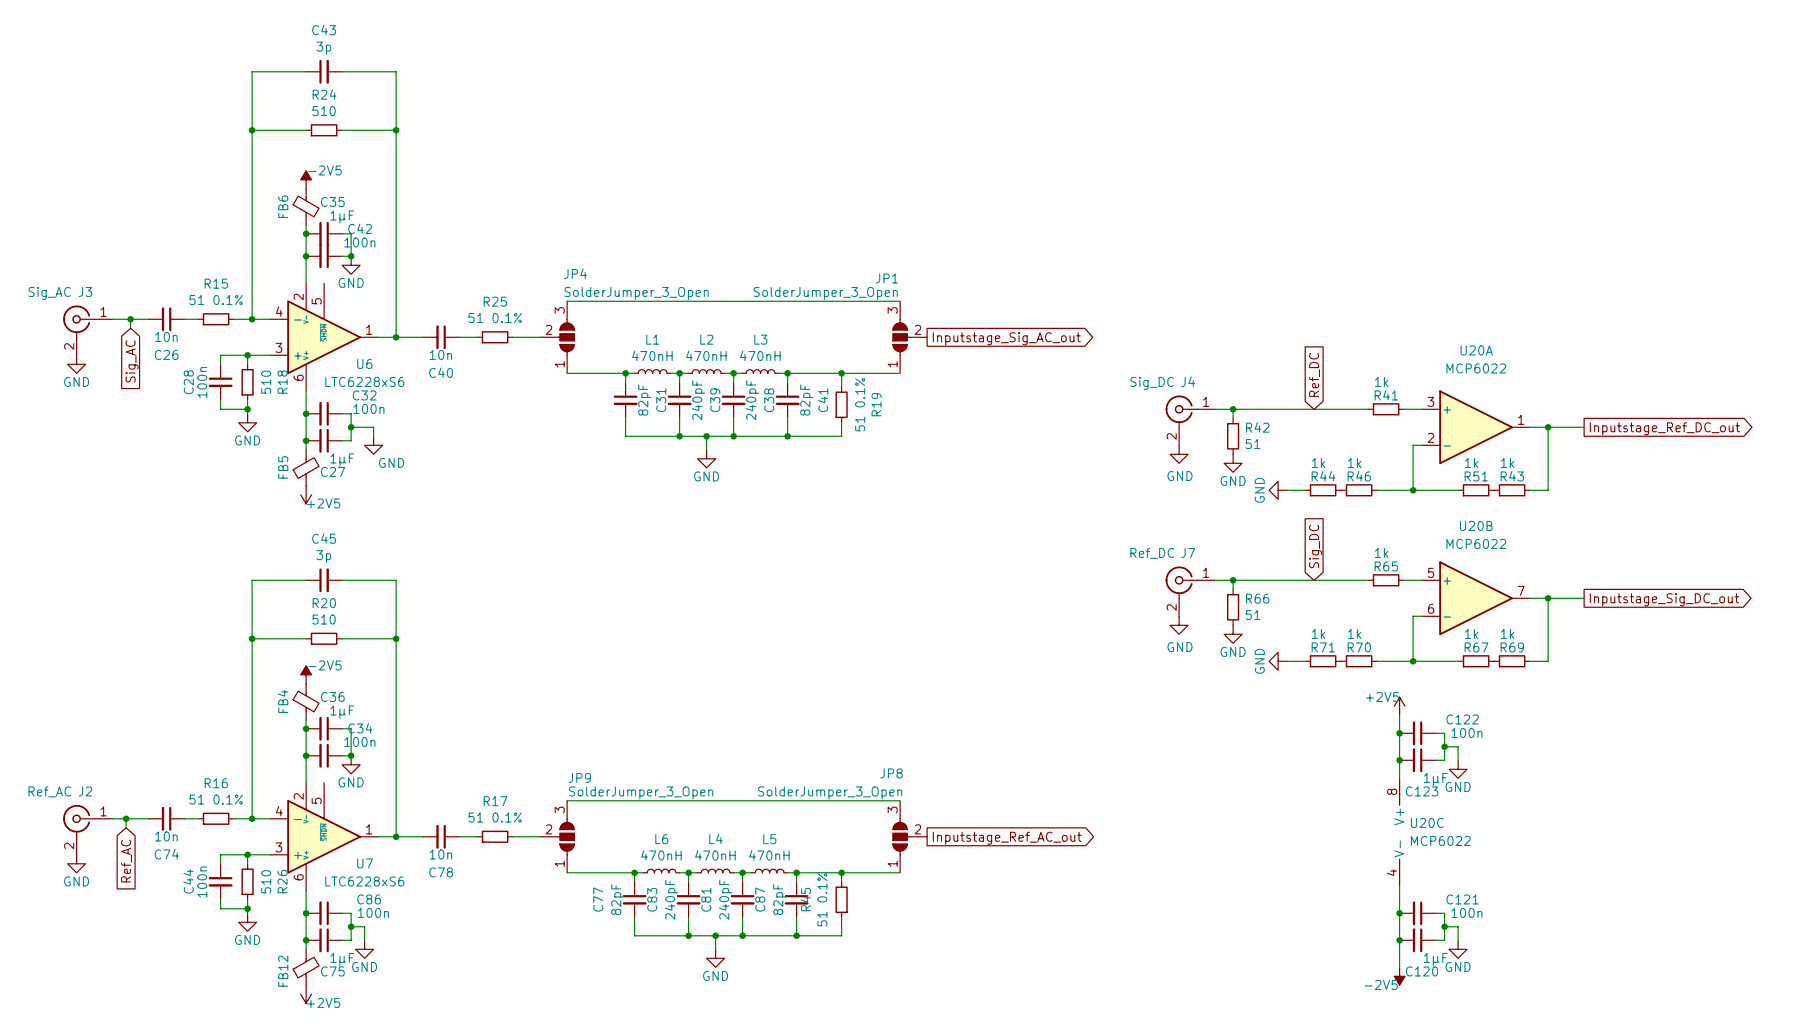
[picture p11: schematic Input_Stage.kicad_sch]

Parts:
C26, C40, C74, C78: 10n; C_0402_1005Metric; LCSC C15195
C27, C35, C36, C75, C120, C123: 1µF; C_0402_1005Metric; LCSC C52923
C28, C32, C34, C42, C44, C86, C121, C122: 100n; C_0402_1005Metric; LCSC C1525
C31, C41, C77, C87: 82pF; C_0402_1005Metric; LCSC C162123
C38, C39, C81, C83: 240pF; C_0603_1608Metric; LCSC C519400
C43, C45: 3p; C_0402_1005Metric; LCSC C88891
FB4, FB5, FB6, FB12: Ferrite_Bead_Small; L_0603_1608Metric; LCSC C1002
J2: Ref_AC; SMA_edge
J3: Sig_AC; SMA_edge
J4: Sig_DC; SMA_edge
J7: Ref_DC; SMA_edge
JP1, JP4, JP8, JP9: SolderJumper_3_Open; 0603_solderbridge3
L1, L2, L3, L4, L5, L6: 470nH; AISC-0805_Inductor; LCSC C127457
R15, R16, R17, R19, R25, R45: 51 0.1%; R_0402_1005Metric; LCSC C445570
R18, R20, R24, R26: 510; R_0402_1005Metric; LCSC C25170
R41, R43, R44, R46, R51, R65, R67, R69, R70, R71: 1k; R_0402_1005Metric; LCSC C11702
R42, R66: 51; R_0402_1005Metric; LCSC C25125
U6, U7: LTC6228xS6; TSOT-23-6
U20: MCP6022; SOIC-8_3.9x4.9mm_P1.27mm; LCSC C57639

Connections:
+2V5: C122.2, C123.2, FB5.1, FB12.1, U20.8 (V+); also elsewhere on the board
-2V5: C120.2, C121.2, FB4.1, FB6.1, U20.4 (V-); also elsewhere on the board
GND: C27.1, C28.2, C31.2, C32.1, C34.1, C35.1, C36.1, C38.2, C39.2, C41.2, C42.1, C44.2, C75.1, C77.2, C81.2, C83.2, C86.1, C87.2, C120.1, C121.1, C122.1, C123.1, J2.2 (Ext), J3.2 (Ext), J4.2 (Ext), J7.2 (Ext), R18.1, R19.1, R26.1, R42.2, R44.1, R45.1, R66.2, R71.1; also elsewhere on the board
Inputstage_Ref_AC_out: JP8.2 (C); also elsewhere on the board
Inputstage_Ref_DC_out: R43.2, U20.1; also elsewhere on the board
Inputstage_Sig_AC_out: JP1.2 (C); also elsewhere on the board
Inputstage_Sig_DC_out: R69.2, U20.7; also elsewhere on the board
unnamed: C26.1, R15.1
unnamed: C27.2, C32.2, FB5.2, U6.6 (V+)
unnamed: C28.1, R18.2, U6.3 (+)
unnamed: C31.1, JP4.1 (A), L1.1
unnamed: C34.2, C36.2, FB4.2, U7.2 (V-)
unnamed: C35.2, C42.2, FB6.2, U6.2 (V-)
unnamed: C38.1, L2.2, L3.1
unnamed: C39.1, L1.2, L2.1
unnamed: C40.1, R25.1
unnamed: C40.2, C43.2, R24.2, U6.1
unnamed: C41.1, JP1.1 (A), L3.2, R19.2
unnamed: C43.1, R15.2, R24.1, U6.4 (-)
unnamed: C44.1, R26.2, U7.3 (+)
unnamed: C45.1, R16.2, R20.1, U7.4 (-)
unnamed: C45.2, C78.2, R20.2, U7.1
unnamed: C74.1, R16.1
unnamed: C75.2, C86.2, FB12.2, U7.6 (V+)
unnamed: C77.1, JP9.1 (A), L6.2
unnamed: C78.1, R17.1
unnamed: C81.1, L4.1, L5.2
unnamed: C83.1, L4.2, L6.1
unnamed: C87.1, JP8.1 (A), L5.1, R45.2
unnamed: JP1.3 (B), JP4.3 (B)
unnamed: JP4.2 (C), R25.2
unnamed: JP8.3 (B), JP9.3 (B)
unnamed: JP9.2 (C), R17.2
unnamed: R41.2, U20.3 (+)
unnamed: R43.1, R51.2
unnamed: R44.2, R46.1
unnamed: R46.2, R51.1, U20.2 (-)
unnamed: R65.2, U20.5 (+)
unnamed: R67.1, R70.2, U20.6 (-)
unnamed: R67.2, R69.1
unnamed: R70.1, R71.2
Ref_AC: C74.2, J2.1 (In)
Ref_DC: J4.1 (In), R41.1, R42.1
Sig_AC: C26.2, J3.1 (In)
Sig_DC: J7.1 (In), R65.1, R66.1

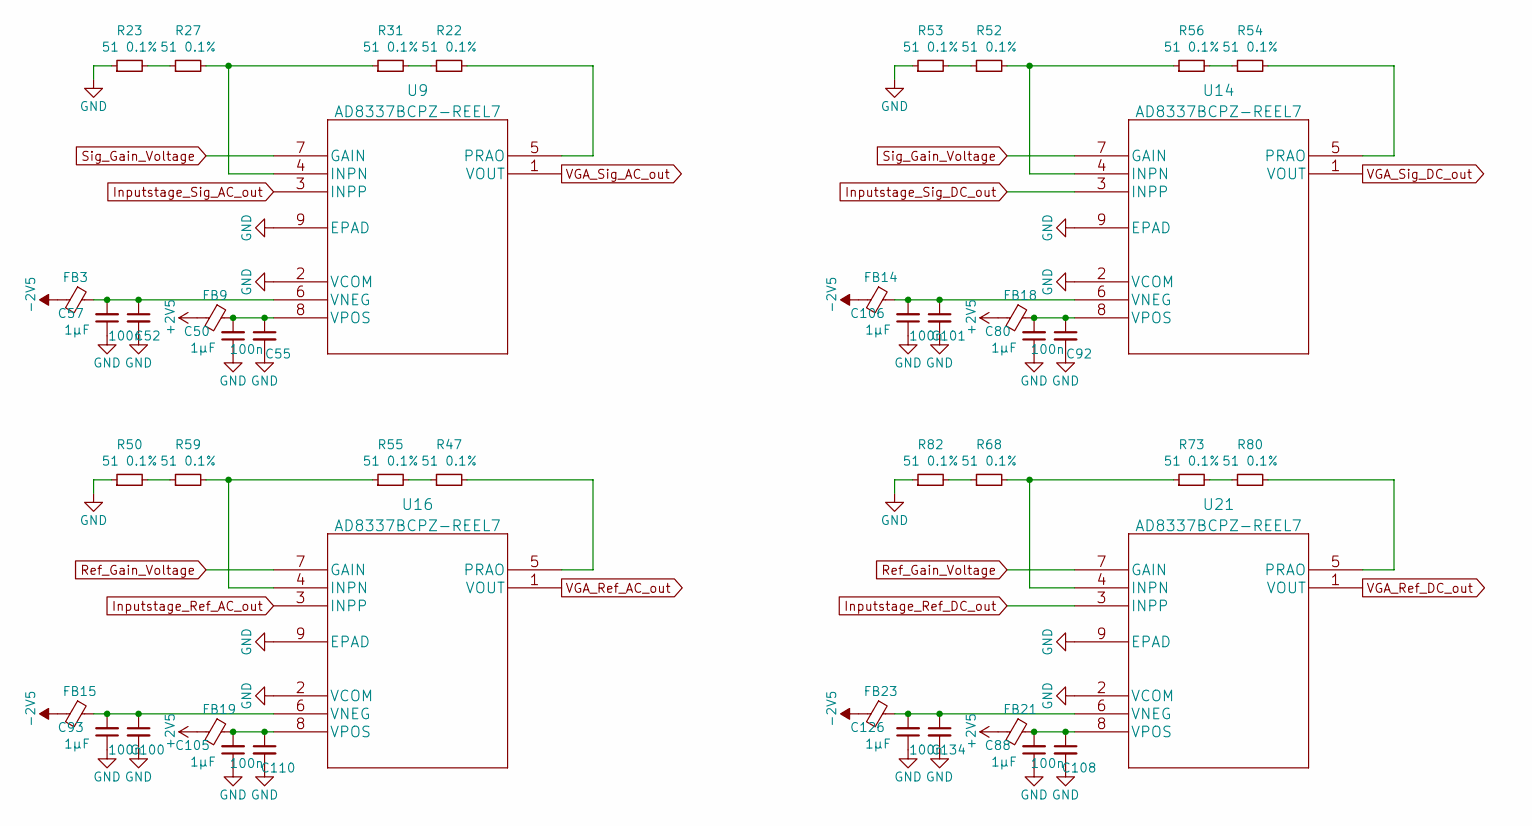
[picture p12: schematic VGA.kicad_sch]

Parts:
C50, C57, C80, C88, C93, C105, C106, C126: 1µF; C_0402_1005Metric; LCSC C52923
C52, C55, C92, C100, C101, C108, C110, C134: 100n; C_0402_1005Metric; LCSC C1525
FB3, FB9, FB14, FB15, FB18, FB19, FB21, FB23: Ferrite_Bead_Small; L_0603_1608Metric; LCSC C1002
R22, R23, R27, R31, R47, R50, R52, R53, R54, R55, R56, R59, R68, R73, R80, R82: 51 0.1%; R_0402_1005Metric; LCSC C445570
U9, U14, U16, U21: AD8337BCPZ-REEL7; LFCSP-8-1EP_3x3mm_P0.5mm_EP1.45x1.74mm

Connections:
+2V5: FB9.2, FB18.2, FB19.2, FB21.2; also elsewhere on the board
-2V5: FB3.2, FB14.2, FB15.2, FB23.2; also elsewhere on the board
GND: C50.1, C52.2, C55.2, C57.1, C80.1, C88.1, C92.2, C93.1, C100.2, C101.2, C105.1, C106.1, C108.2, C110.2, C126.1, C134.2, R23.1, R50.1, R53.1, R82.1, U9.2 (VCOM), U9.9 (EPAD), U14.2 (VCOM), U14.9 (EPAD), U16.2 (VCOM), U16.9 (EPAD), U21.2 (VCOM), U21.9 (EPAD); also elsewhere on the board
Inputstage_Ref_AC_out: U16.3 (INPP); also elsewhere on the board
Inputstage_Ref_DC_out: U21.3 (INPP); also elsewhere on the board
Inputstage_Sig_AC_out: U9.3 (INPP); also elsewhere on the board
Inputstage_Sig_DC_out: U14.3 (INPP); also elsewhere on the board
unnamed: C50.2, C55.1, FB9.1, U9.8 (VPOS)
unnamed: C52.1, C57.2, FB3.1, U9.6 (VNEG)
unnamed: C80.2, C92.1, FB18.1, U14.8 (VPOS)
unnamed: C93.2, C100.1, FB15.1, U16.6 (VNEG)
unnamed: C101.1, C106.2, FB14.1, U14.6 (VNEG)
unnamed: C105.2, C110.1, FB19.1, U16.8 (VPOS)
unnamed: C88.2, C108.1, FB21.1, U21.8 (VPOS)
unnamed: C126.2, C134.1, FB23.1, U21.6 (VNEG)
unnamed: R22.1, R31.2
unnamed: R22.2, U9.5 (PRAO)
unnamed: R23.2, R27.1
unnamed: R27.2, R31.1, U9.4 (INPN)
unnamed: R47.1, R55.2
unnamed: R47.2, U16.5 (PRAO)
unnamed: R50.2, R59.1
unnamed: R52.1, R53.2
unnamed: R52.2, R56.1, U14.4 (INPN)
unnamed: R54.1, R56.2
unnamed: R54.2, U14.5 (PRAO)
unnamed: R55.1, R59.2, U16.4 (INPN)
unnamed: R68.1, R82.2
unnamed: R68.2, R73.1, U21.4 (INPN)
unnamed: R73.2, R80.1
unnamed: R80.2, U21.5 (PRAO)
Ref_Gain_Voltage: U16.7 (GAIN), U21.7 (GAIN); also elsewhere on the board
Sig_Gain_Voltage: U9.7 (GAIN), U14.7 (GAIN); also elsewhere on the board
VGA_Ref_AC_out: U16.1 (VOUT); also elsewhere on the board
VGA_Ref_DC_out: U21.1 (VOUT); also elsewhere on the board
VGA_Sig_AC_out: U9.1 (VOUT); also elsewhere on the board
VGA_Sig_DC_out: U14.1 (VOUT); also elsewhere on the board


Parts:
C60, C64, C65, C66, C76, C79, C84, C85, C90, C91, C95, C98, C99, C102, C113, C115, C117, C124, C127, C133, C149, C150, C151, C153, C154, C155: 100n; C_0402_1005Metric; LCSC C1525
C63, C112, C114, C116: 10uF; C_1206_3216Metric; LCSC C13585
C82, C89, C152, C156: 1µF; C_0402_1005Metric; LCSC C52923
FB10, FB11, FB13, FB20, FB22, FB24: Ferrite_Bead_Small; L_0603_1608Metric; LCSC C1002
J5: DC_absorption; SMA_edge
J6: Signal; SMA_edge
J8: DC_balance_error; SMA_edge
R36, R61: 24.3; R_0402_1005Metric; LCSC C321400
R48, R62, R63: 51 0.1%; R_0402_1005Metric; LCSC C445570
R99, R100, R103, R104, R105: 1k; R_0402_1005Metric; LCSC C11702
R101, R106: 10k; R_0402_1005Metric; LCSC C25744
R102, R107: 100k; R_0402_1005Metric; LCSC C25741
R108: 22; R_0402_1005Metric
U10, U15, U17: LT6402IUD-6-PBF; QFN-16-1EP_3x3mm_P0.5mm_EP1.45x1.45mm_ThermalVias
U12: ADT1-1+; JLCPCB C2683432
U29: MCP6022; SOIC-8_3.9x4.9mm_P1.27mm; LCSC C57639
U30, U31: SGM4157YC6; SC-60; LCSC C124895

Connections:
+2V5: C150.1, C151.2, C152.2, C155.1, FB10.1, FB13.1, FB20.1, U29.8 (V+), U30.5 (V+), U31.5 (V+); also elsewhere on the board
-2V5: C149.1, C153.2, C154.1, C156.2, FB11.2, FB22.2, FB24.2, U29.4 (V-), U30.2 (GND), U31.2 (GND); also elsewhere on the board
/Substractor/Signal_N: C64.1, U12.1 (Pri)
/Substractor/Signal_P: C117.1, U12.3 (Pri)
GND: C60.2, C63.2, C65.2, C66.2, C76.2, C79.2, C82.2, C84.2, C85.2, C89.2, C90.2, C91.2, C95.2, C98.2, C99.2, C102.2, C112.2, C113.2, C114.2, C115.2, C116.2, C124.2, C127.2, C133.2, C149.2, C150.2, C151.1, C152.1, C153.1, C154.2, C155.2, C156.1, J5.2 (Ext), J6.2 (Ext), J8.2 (Ext), R100.1, R104.2, R105.1, U10.2 (VOCM), U12.6 (Sec), U15.2 (VOCM), U17.2 (VOCM); also elsewhere on the board
Inputstage_Ref_DC_out: U15.13 (-INB), U15.14 (-INA); also elsewhere on the board
Inputstage_Sig_DC_out: U15.15 (+INB), U15.16 (+INA); also elsewhere on the board
unnamed: C64.2, R36.2
unnamed: C76.1, C82.1, C84.1, C85.1, FB11.1, U15.4 (VEEA), U15.9 (VEEB), U15.11 (*ENABLE), U15.12 (VEEC), U15.17 (EPAD)
unnamed: C79.1, C89.1, C90.1, C91.1, FB13.2, U15.1 (VCCC), U15.3 (VCCA), U15.10 (VCCB)
unnamed: C98.1, C102.1, C112.1, C124.1, FB24.1, U17.4 (VEEA), U17.9 (VEEB), U17.11 (*ENABLE), U17.12 (VEEC), U17.17 (EPAD)
unnamed: C63.1, C65.1, C95.1, C113.1, FB10.2, U10.1 (VCCC), U10.3 (VCCA), U10.10 (VCCB)
unnamed: C60.1, C66.1, C114.1, C115.1, FB22.1, U10.4 (VEEA), U10.9 (VEEB), U10.11 (*ENABLE), U10.12 (VEEC), U10.17 (EPAD)
unnamed: C99.1, C116.1, C127.1, C133.1, FB20.2, U17.1 (VCCC), U17.3 (VCCA), U17.10 (VCCB)
unnamed: C117.2, R61.2
unnamed: J5.1 (In), R48.2
unnamed: J6.1 (In), U12.4 (Sec)
unnamed: J8.1 (In), R63.2
unnamed: R36.1, U10.8 (-OUT)
unnamed: R48.1, U31.4 (COM)
unnamed: R61.1, U10.5 (+OUT)
unnamed: R62.1, U17.5 (+OUT)
unnamed: R62.2, R99.1, U30.1 (OUT_0)
unnamed: R63.1, U17.8 (-OUT)
unnamed: R99.2, U29.3 (+)
unnamed: R100.2, R101.2, R102.2, U29.2 (-)
unnamed: R101.1, R102.1, U29.1, U30.3 (OUT_1)
unnamed: R103.1, R108.2, U31.1 (OUT_0)
unnamed: R103.2, U29.5 (+)
unnamed: R105.2, R106.2, R107.2, U29.6 (-)
unnamed: R106.1, R107.1, U29.7, U31.3 (OUT_1)
unnamed: R104.1, U15.5 (+OUT)
unnamed: R108.1, U15.8 (-OUT)
PID_error: U30.4 (COM); also elsewhere on the board
Phaseshifter_Ref_AC_out: U10.15 (+INB), U10.16 (+INA); also elsewhere on the board
Phaseshifter_Sig_AC_out: U10.13 (-INB), U10.14 (-INA); also elsewhere on the board
QD: U30.6 (IN); also elsewhere on the board
QE: U31.6 (IN); also elsewhere on the board
VGA_Ref_DC_out: U17.15 (+INB), U17.16 (+INA); also elsewhere on the board
VGA_Sig_DC_out: U17.13 (-INB), U17.14 (-INA); also elsewhere on the board


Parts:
C125, C131: 100n; C_0402_1005Metric; LCSC C1525
D16, D17, D18: ZMM3v3; D_MiniMELF; LCSC C8056
R72, R78, R81: 1k; R_0402_1005Metric; LCSC C11702
R74: 10k; R_0402_1005Metric; LCSC C25744
U23: 74HC595; SOIC-16_3.9x9.9mm_P1.27mm; LCSC C5947

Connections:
+2V5: C125.1, R74.2, U23.16 (VCC); also elsewhere on the board
-2V5: C131.1, R72.1, R78.1, R81.1, U23.8 (GND), U23.13 (~OE); also elsewhere on the board
GND: C125.2, C131.2; also elsewhere on the board
unnamed: R74.1, U23.10 (~SRCLR)
PA16: D18.1 (K); also elsewhere on the board
PA27: D16.1 (K); also elsewhere on the board
PA28: D17.1 (K); also elsewhere on the board
QA: U23.15 (QA); also elsewhere on the board
QB: U23.1 (QB); also elsewhere on the board
QC: U23.2 (QC); also elsewhere on the board
QD: U23.3 (QD); also elsewhere on the board
QE: U23.4 (QE); also elsewhere on the board
QF: U23.5 (QF); also elsewhere on the board
QG: U23.6 (QG); also elsewhere on the board
QH: U23.7 (QH); also elsewhere on the board
latch: D16.2 (A), R78.2, U23.12 (RCLK)
ser_clock: D17.2 (A), R81.2, U23.11 (SRCLK)
ser_data: D18.2 (A), R72.2, U23.14 (SER)

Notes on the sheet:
MUX - DAC | Poti -> Ref. Gain
MUX - x1 | x10 -> DC Diff. Gain
MUX - PID | Manual -> Sig. Gain
MUX - DAC | Poti -> PID offset
MUX - x1 | x10 -> PID Error Gain
DAC I2C, SCL
DAC I2C, SDA
MUX - DAC | Poti -> Manual Sig. Gain

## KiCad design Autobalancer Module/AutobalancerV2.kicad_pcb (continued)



Board: 4 copper layers, 100.0 x 100.0 mm, 374 parts (3 on the bottom side), 203 nets.
